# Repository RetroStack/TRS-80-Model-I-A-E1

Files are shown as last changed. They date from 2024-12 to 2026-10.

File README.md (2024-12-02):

# TRS-80 Model 1 (Rev A) Replica - E1

This project is a reverse-engineered PCB created to document the mainboard of the iconic TRS-80 Model 1 (Revision A) computer. Released in 1977, Revision A was the first implementation and features some differences compared to later revisions, including a different Z3 selector, a slightly modified video sync circuit, and a lack of support for 8k dynamic RAM.

The entire project is available under the MIT license.

**NOTE:** The PCB has not yet been validated. Once I am able to fully validate the PCB by producing a board and thoroughly testing it, I will make the Gerber files available. Additionally, I will have some PCBs available in my [store](https://shop.retrostack.org).

## Project Details

### Latest Files

In the "Latest" folder, you'll find the most up-to-date design files, including:

- The [full schematics](/Latest/TRS80_Model_I_A_E1_Schematics.pdf) of the E1 replica which is 1:1 to the original G board.

### Implementation

E1 has been implemented using KiCAD 8. The KiCAD project files are included in this repository.

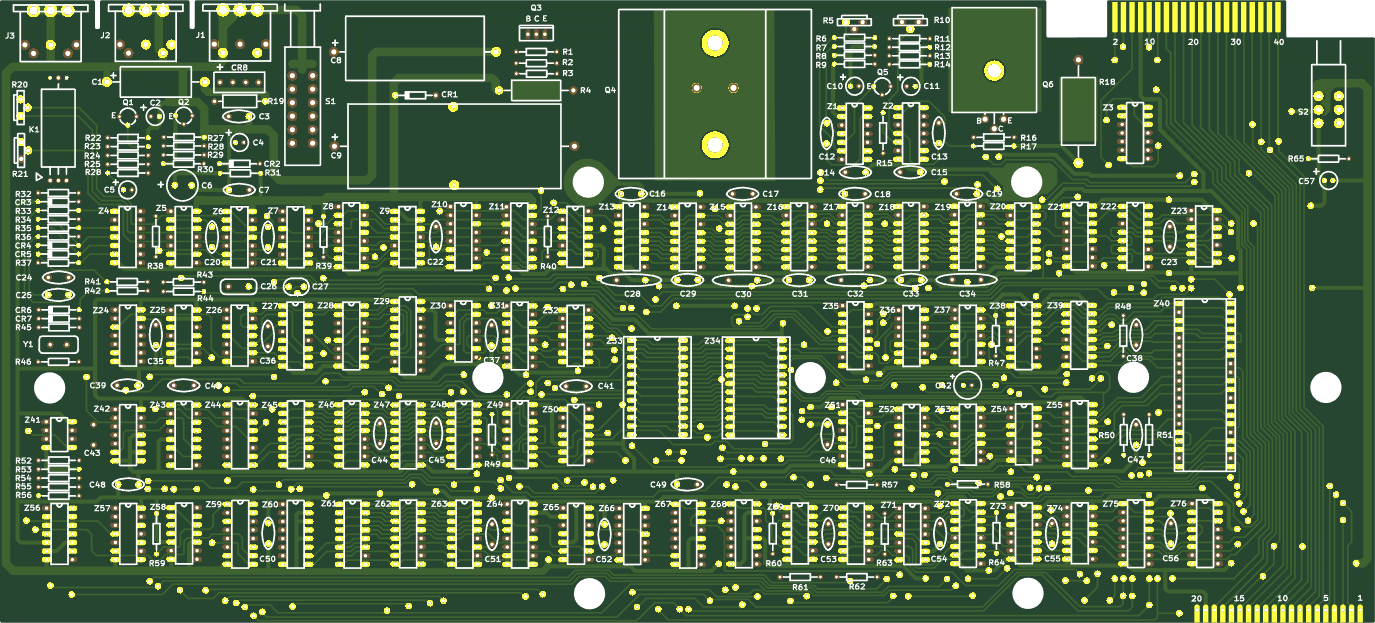
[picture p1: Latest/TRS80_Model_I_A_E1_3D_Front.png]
E1 Replica Front

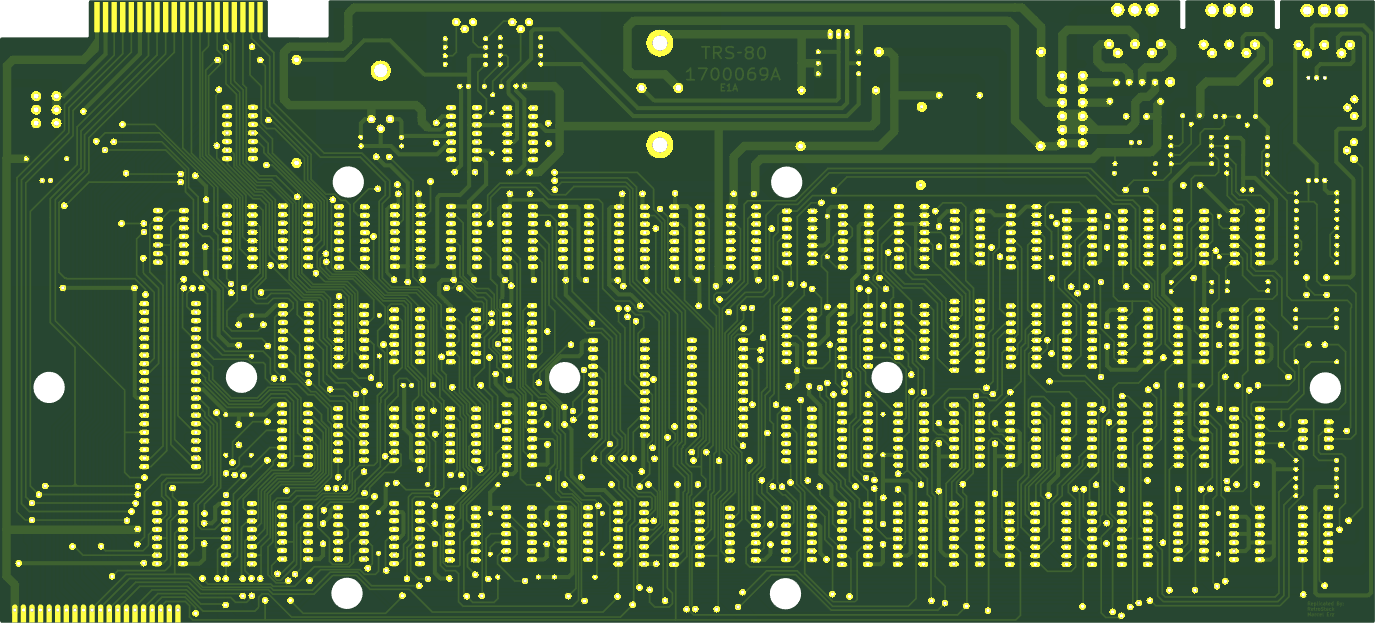
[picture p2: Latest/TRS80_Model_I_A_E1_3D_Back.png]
E1 Replica Back


### RetroStack Libraries

To work with this KiCAD project, you'll need the RetroStack libraries for KiCAD. Please [follow this link](https://www.github.com/RetroStack/KiCAD-Libraries) to access and install these libraries.

## Main TRS-80 Model 1 Repository

For additional resources related to the TRS-80 Model 1, be sure to check out the [central page for the TRS-80 Model 1](https://www.github.com/RetroStack/TRS-80-Model-I) on [RetroStack](https://www.github.com/RetroStack).

## Support this Project

RetroStack is passionate about exploring and preserving the legacy of older computer systems. My work involves creating detailed documentation and videos to share the knowledge. I am also dedicated to reviving these classic systems by reimplementing them and offering replacement parts at no cost. If you're keen on supporting this unique project, I invite you to visit my [Patreon page](https://www.patreon.com/RetroStack). Your support would be immensely valuable and greatly appreciated!

## License

This project is licensed under the MIT License - see the [LICENSE](LICENSE) file for details.

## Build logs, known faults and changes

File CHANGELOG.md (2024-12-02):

# TRS-80 Model 1 (Rev A) Replica - E1 - Changelog

## 30th Nov 2024 - E1A

Completed. Untested.

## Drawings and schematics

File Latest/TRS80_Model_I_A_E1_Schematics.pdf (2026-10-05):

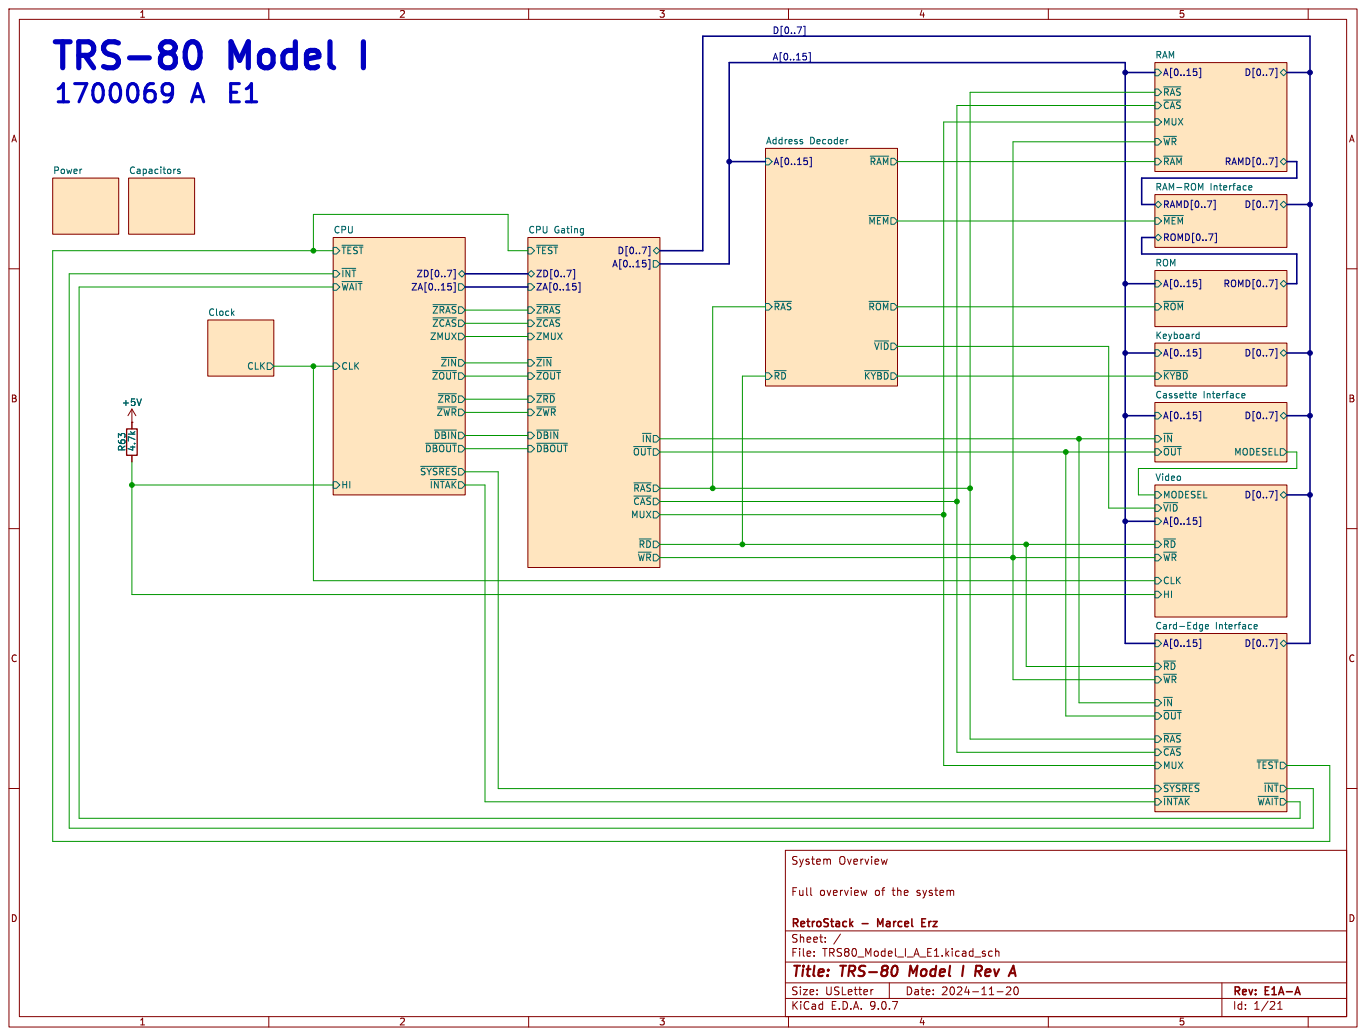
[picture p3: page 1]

RAMD[0..7] RAM-ROM Interface ~{WR}
~{RAM}
D[0..7] MODESEL Cassette Interface ~{RAS}

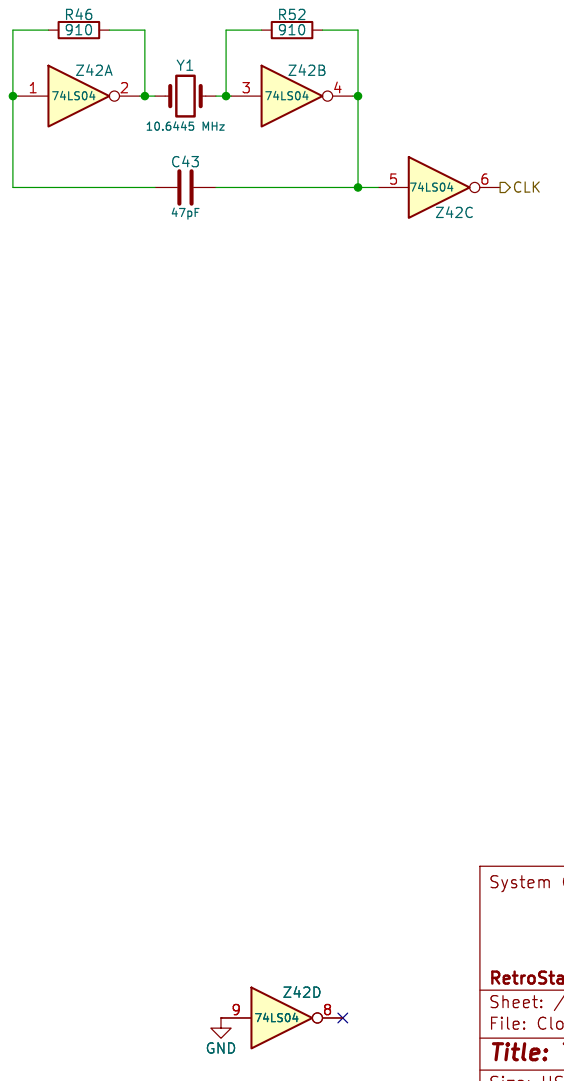
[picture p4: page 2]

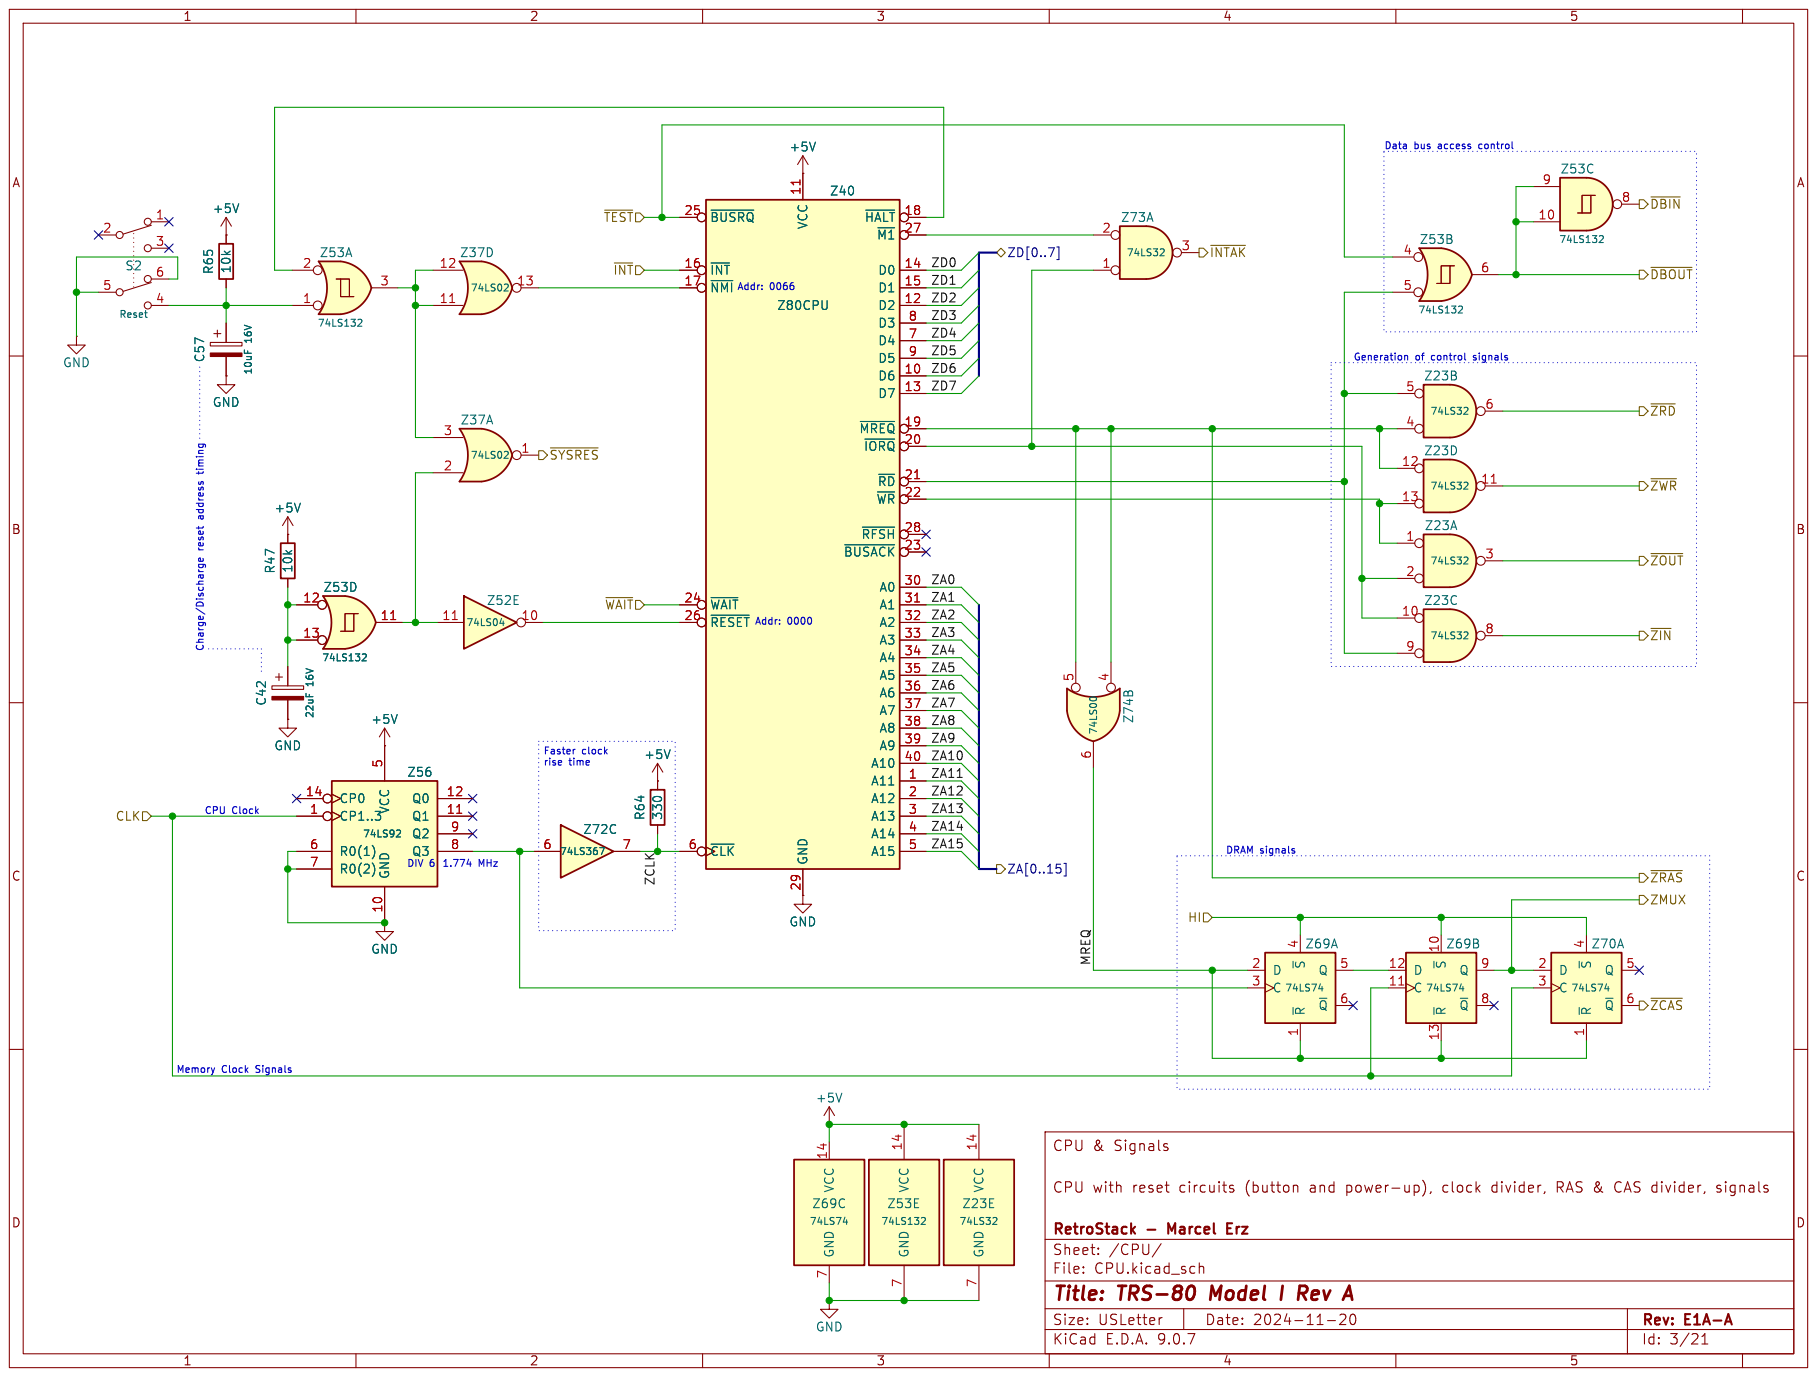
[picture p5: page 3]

rise time CPU Clock

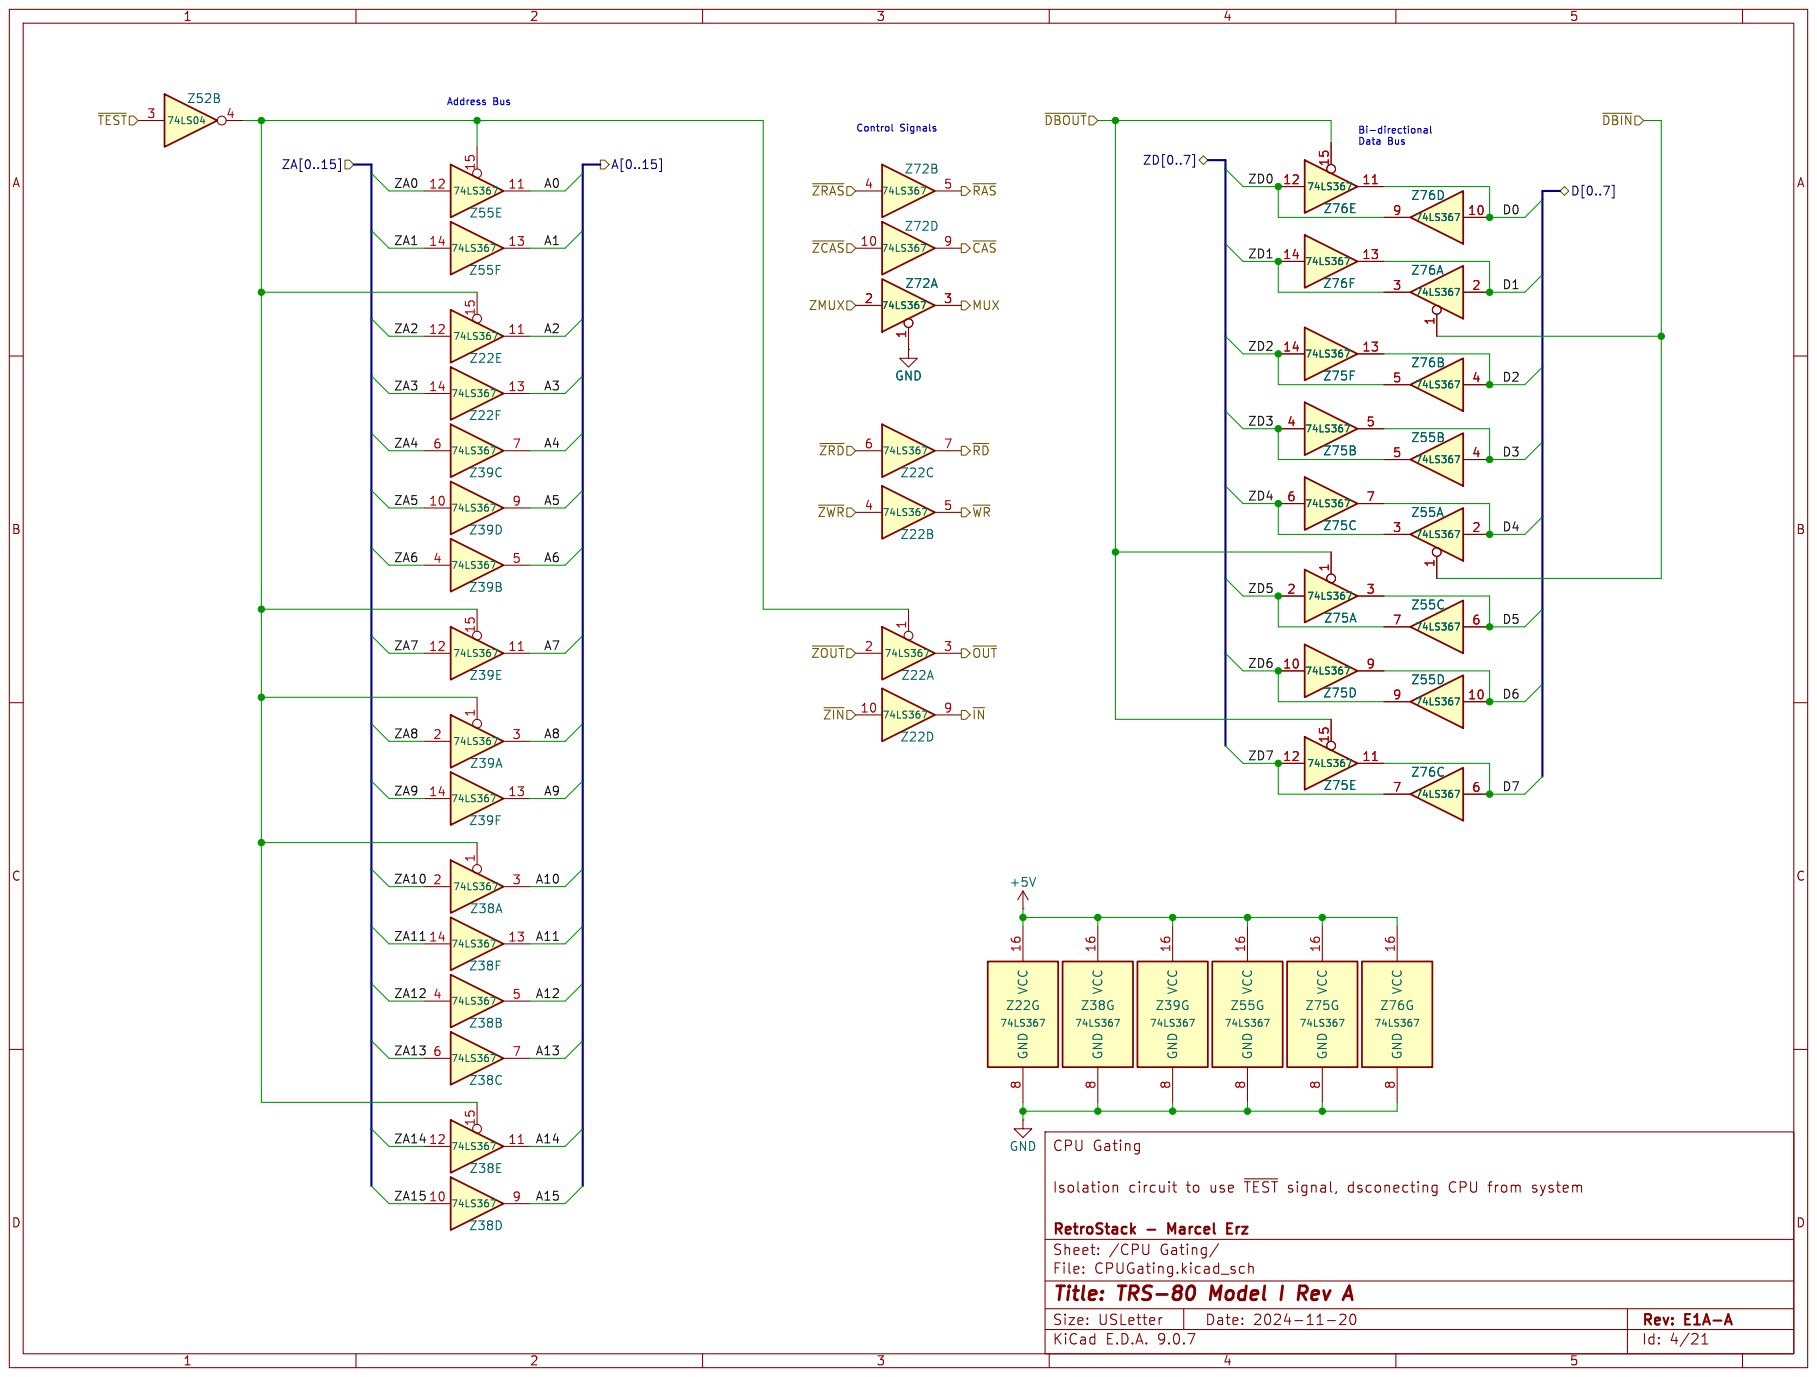
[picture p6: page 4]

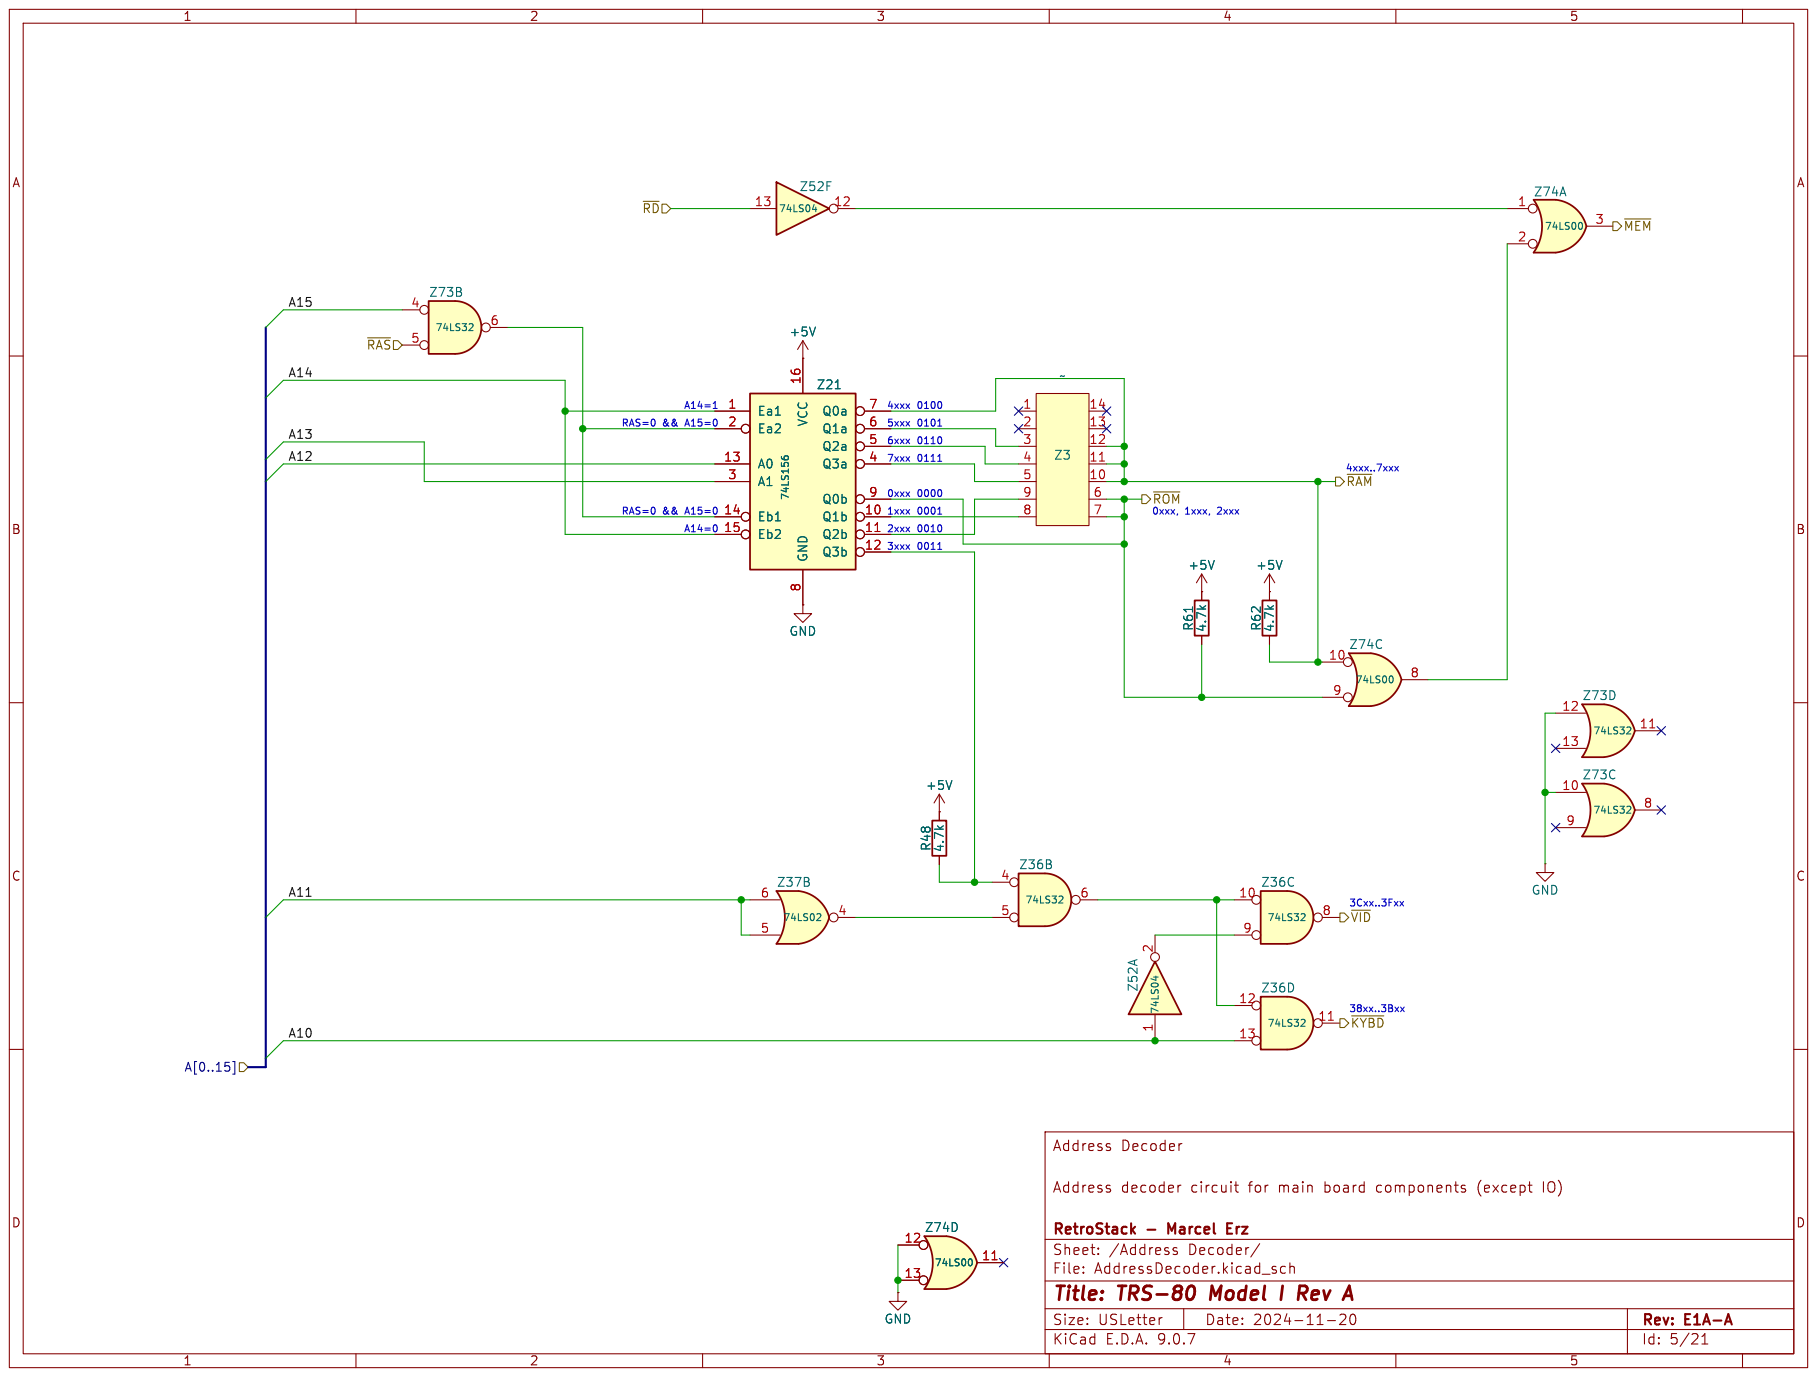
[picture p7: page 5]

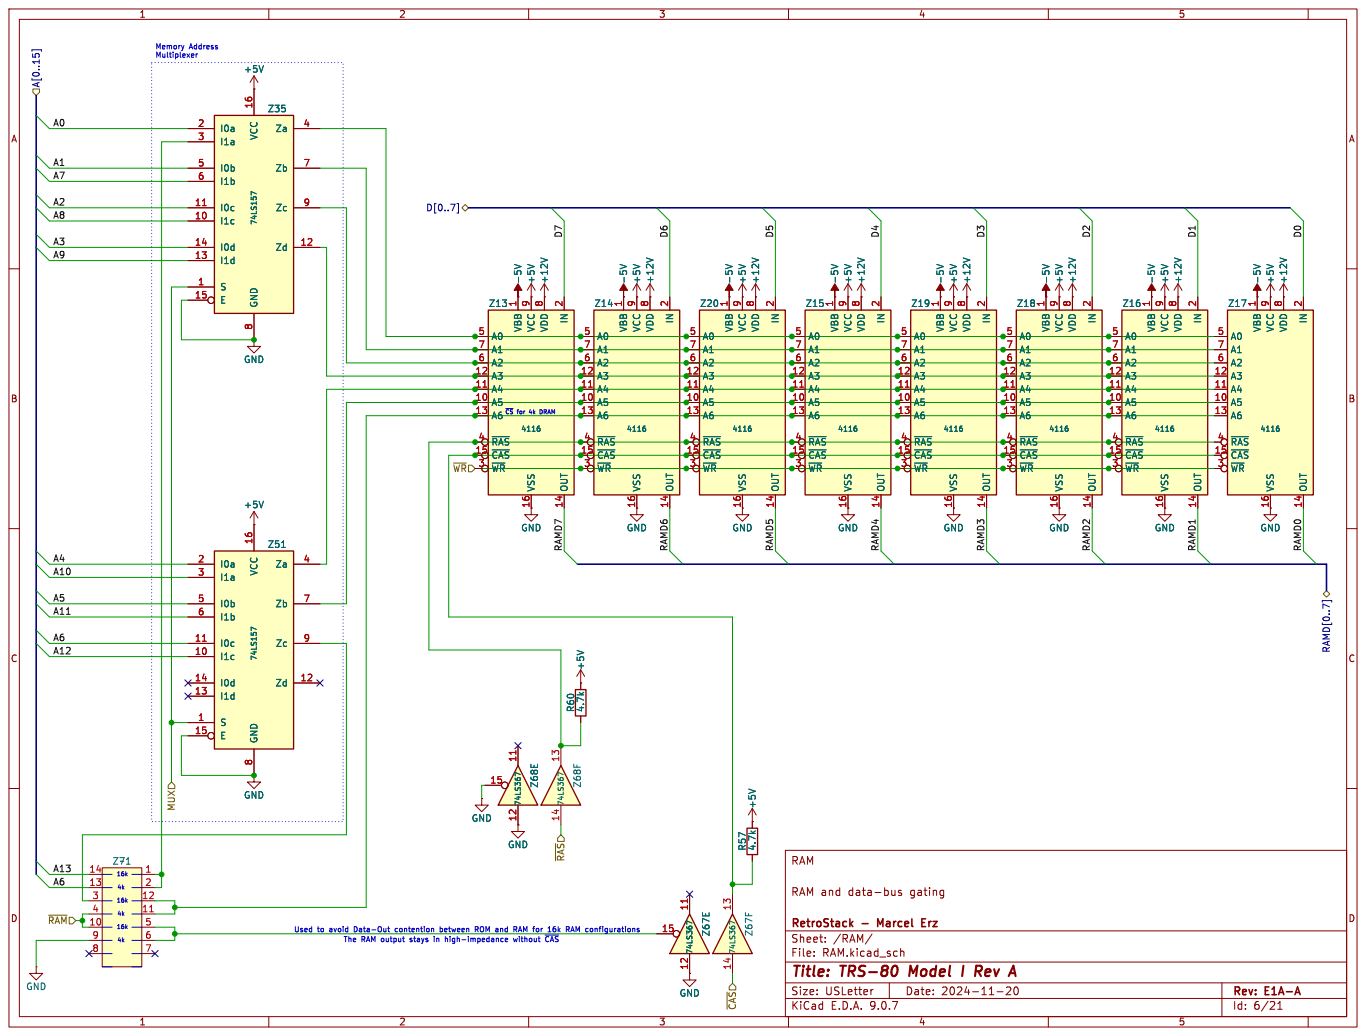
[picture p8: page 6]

8 Za 4 Zb 7 Zc 9 Zd 12 Z35 74LS157 +5V GND

8 Za 4 Zb 7 Zc 9 Zd 12 +5V GND

8 Za 4 Zb 7 Zc 9 Zd 12 GND -5V +5V

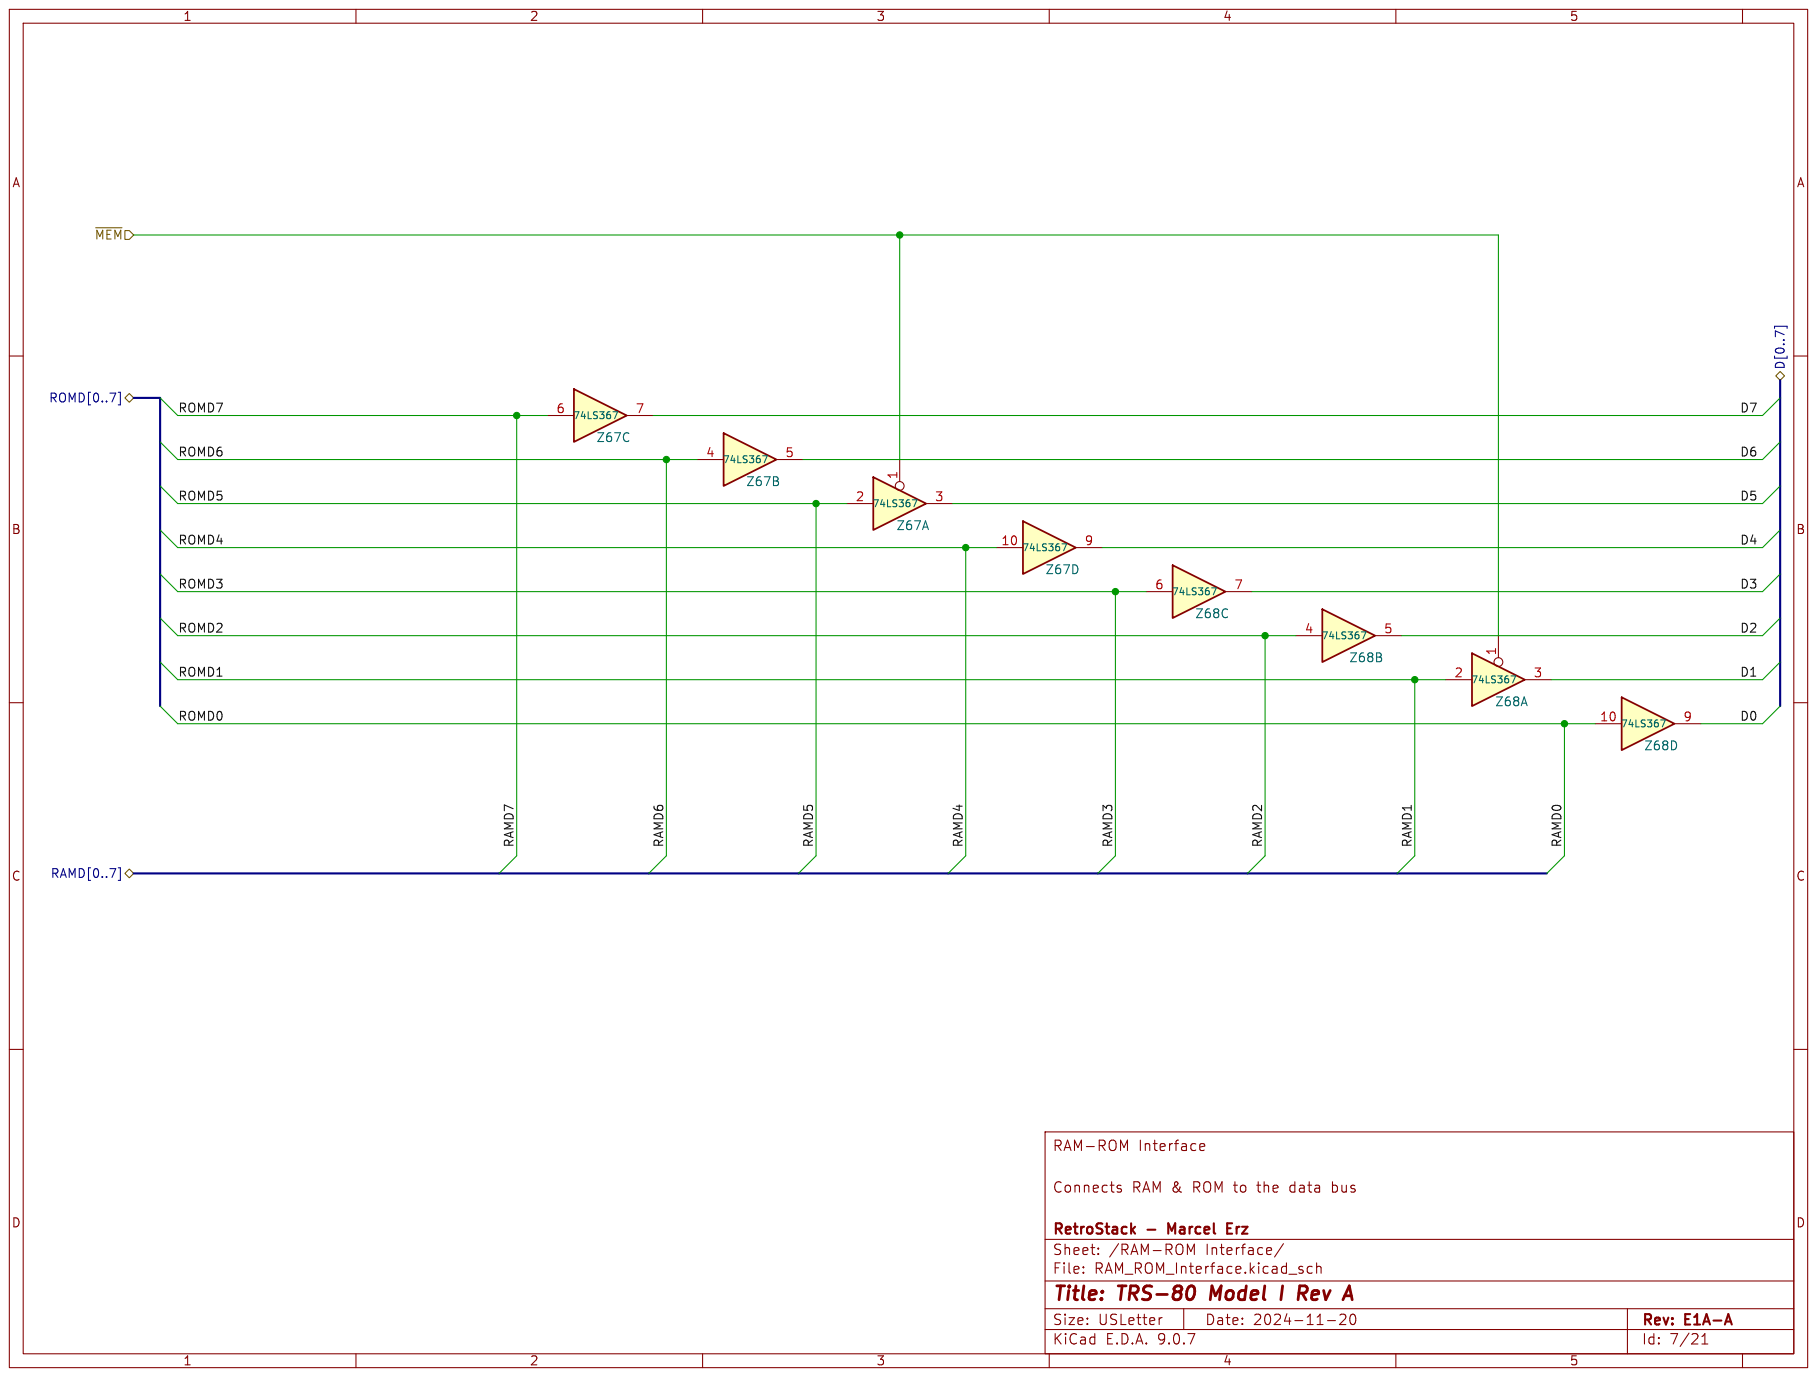
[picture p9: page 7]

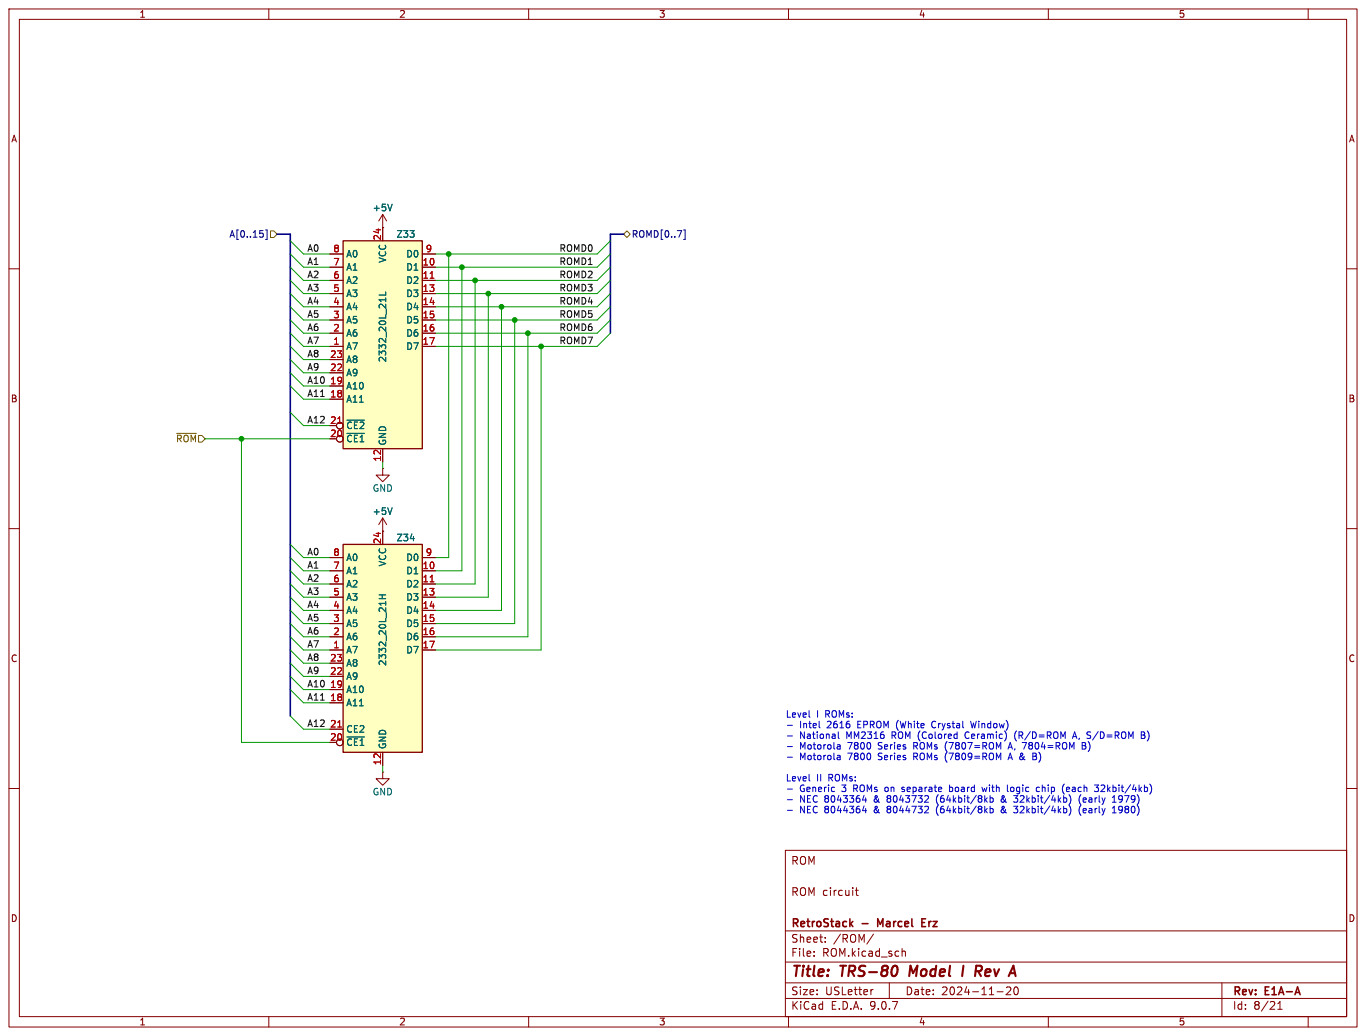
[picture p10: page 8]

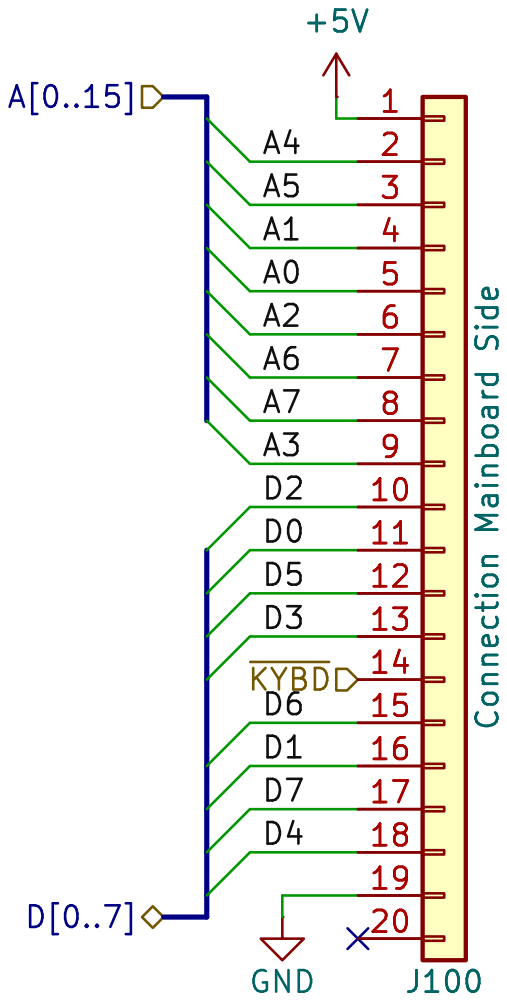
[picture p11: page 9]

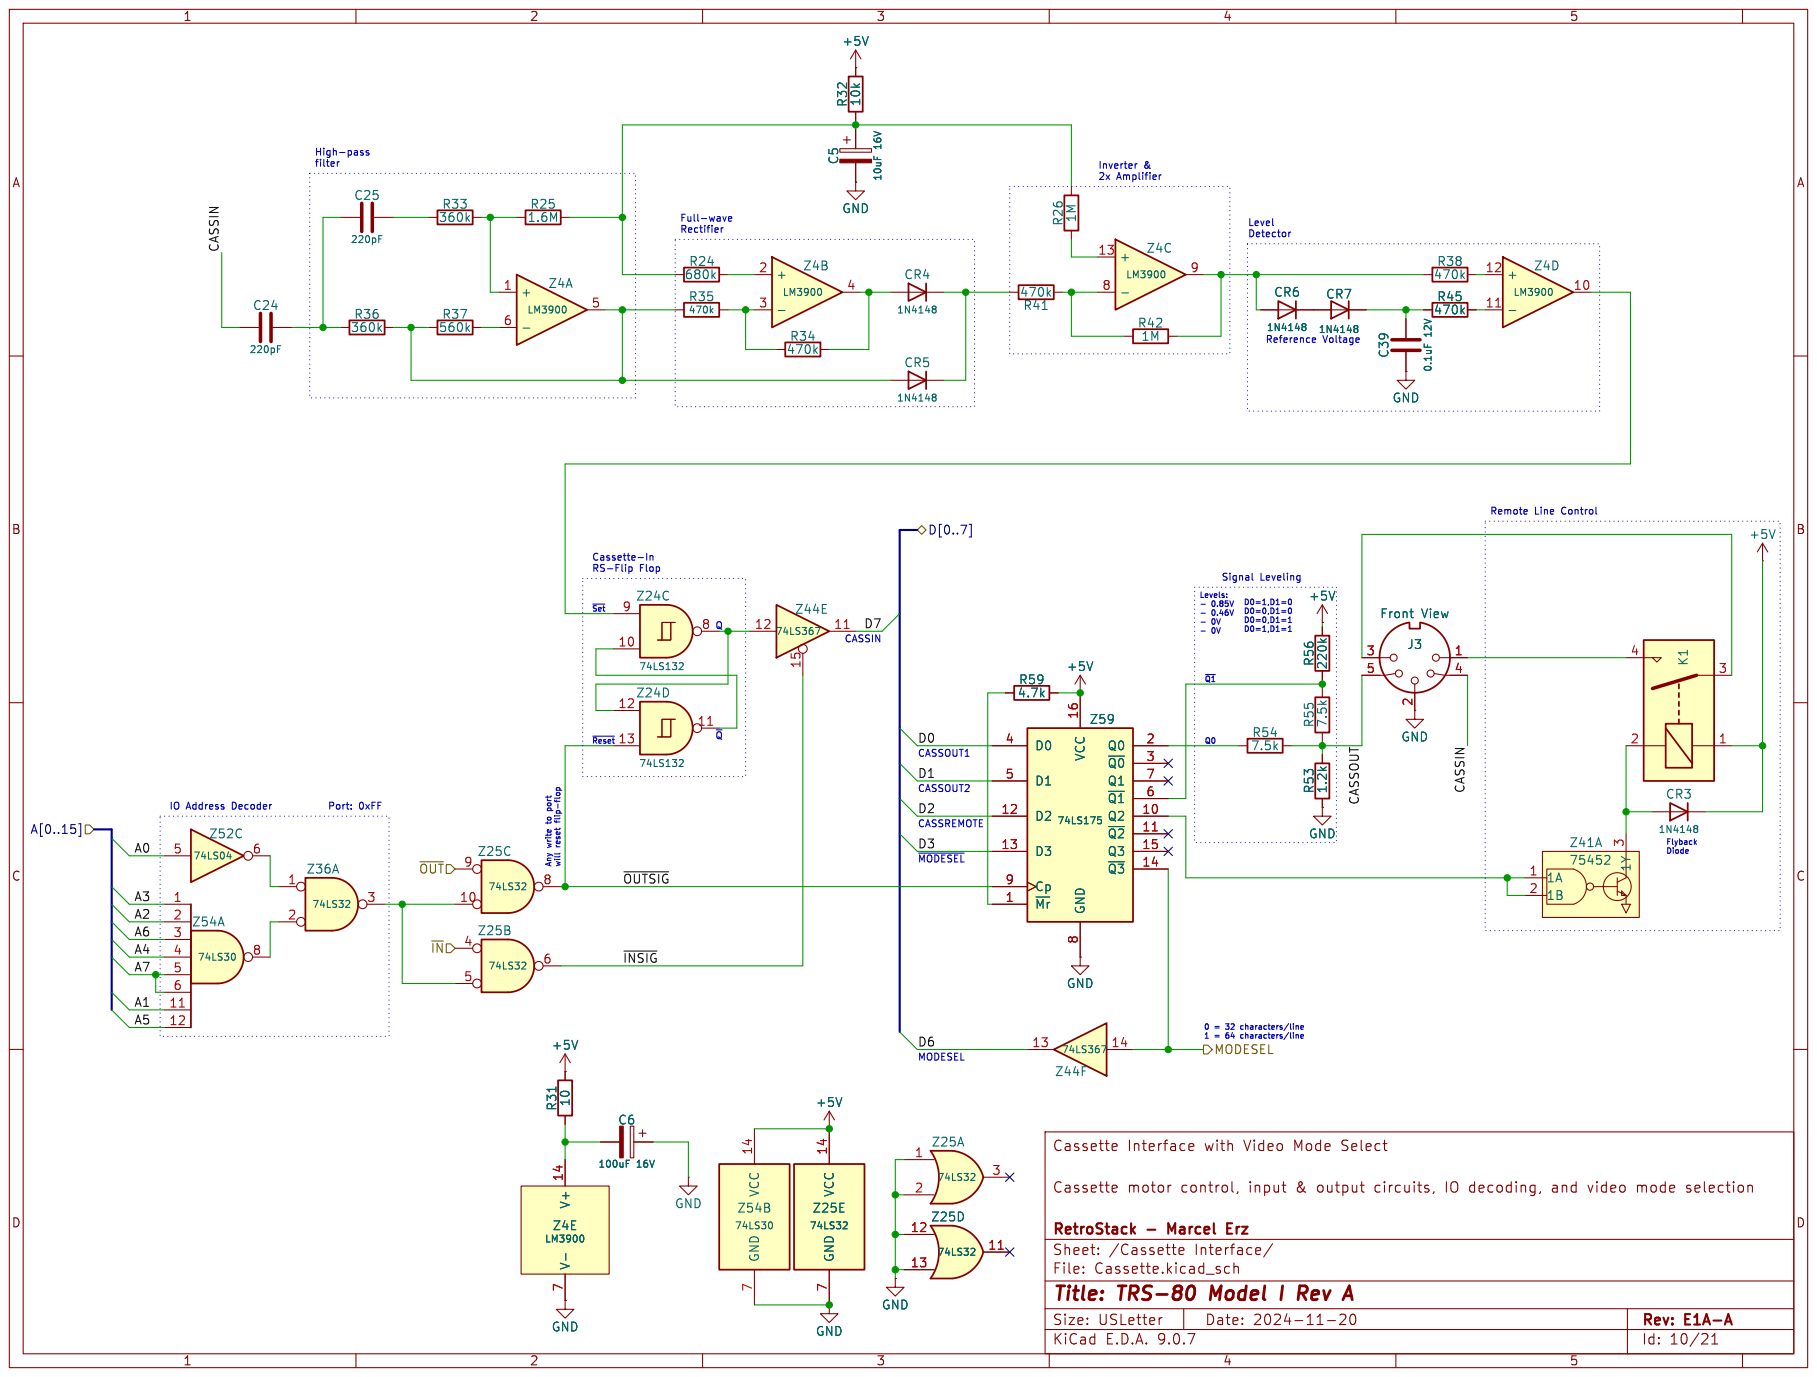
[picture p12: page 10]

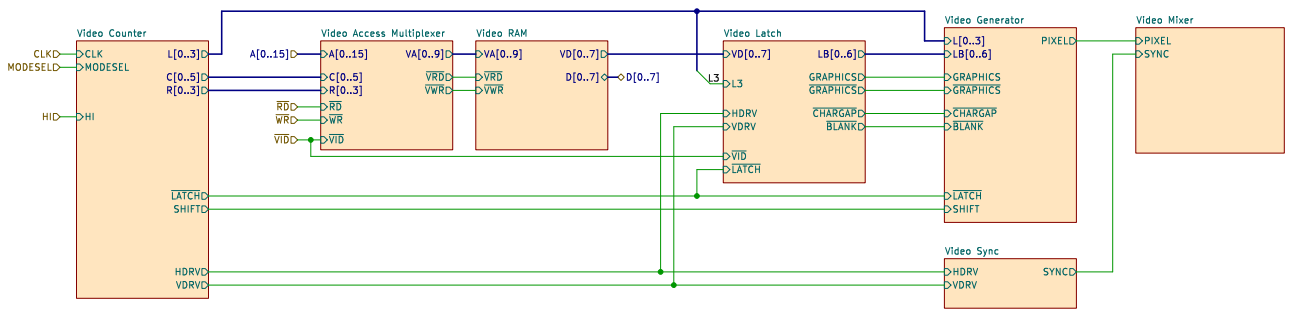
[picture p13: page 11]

LB[0..6] Video Generator D[0..7] MODESELHI CLK

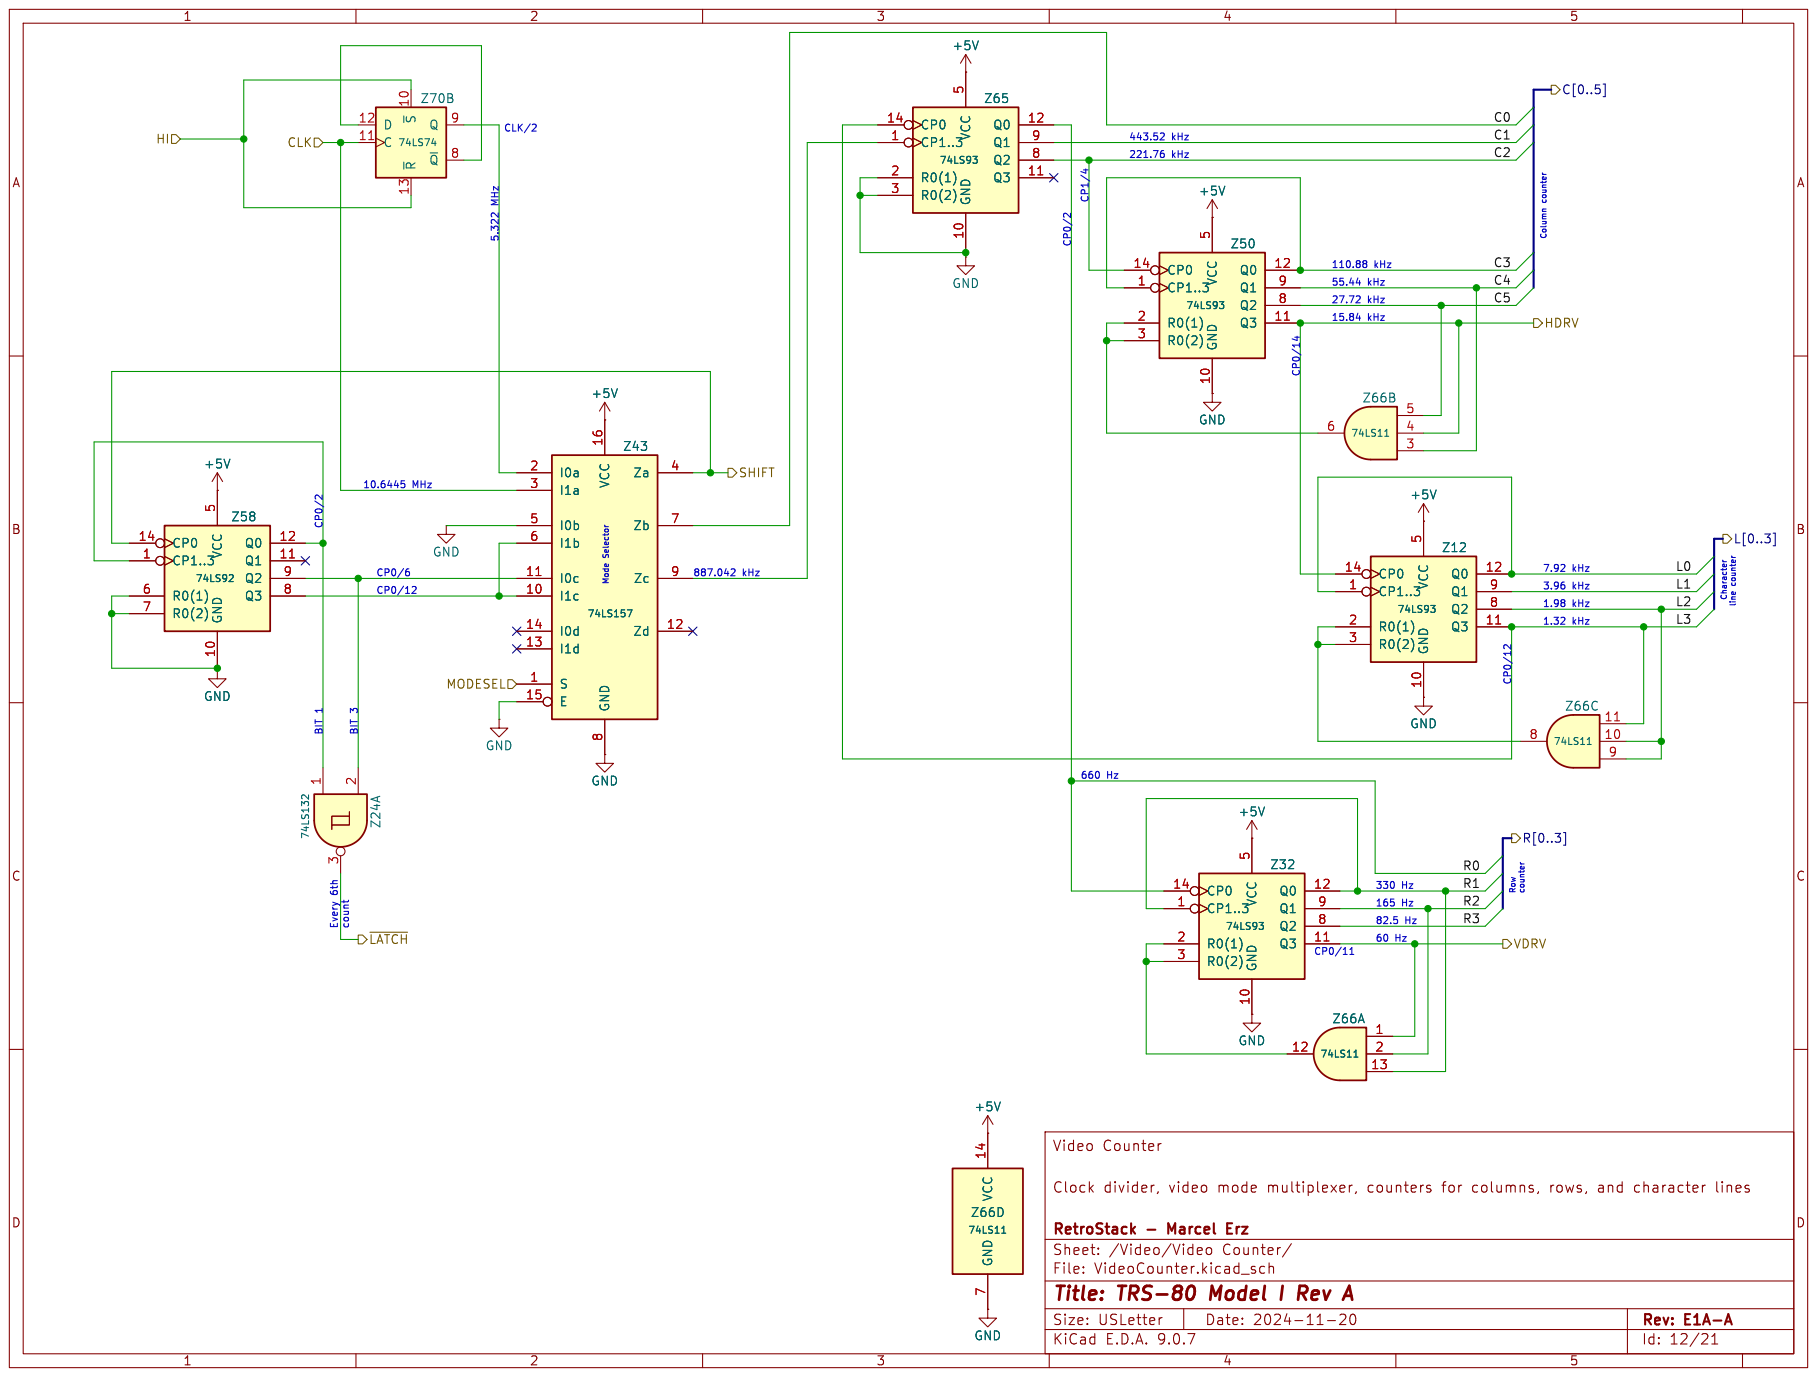
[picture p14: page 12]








12 ~{OUT} 14 ~{INTAK} 16 18 20 22 24 26 28 30 32 34



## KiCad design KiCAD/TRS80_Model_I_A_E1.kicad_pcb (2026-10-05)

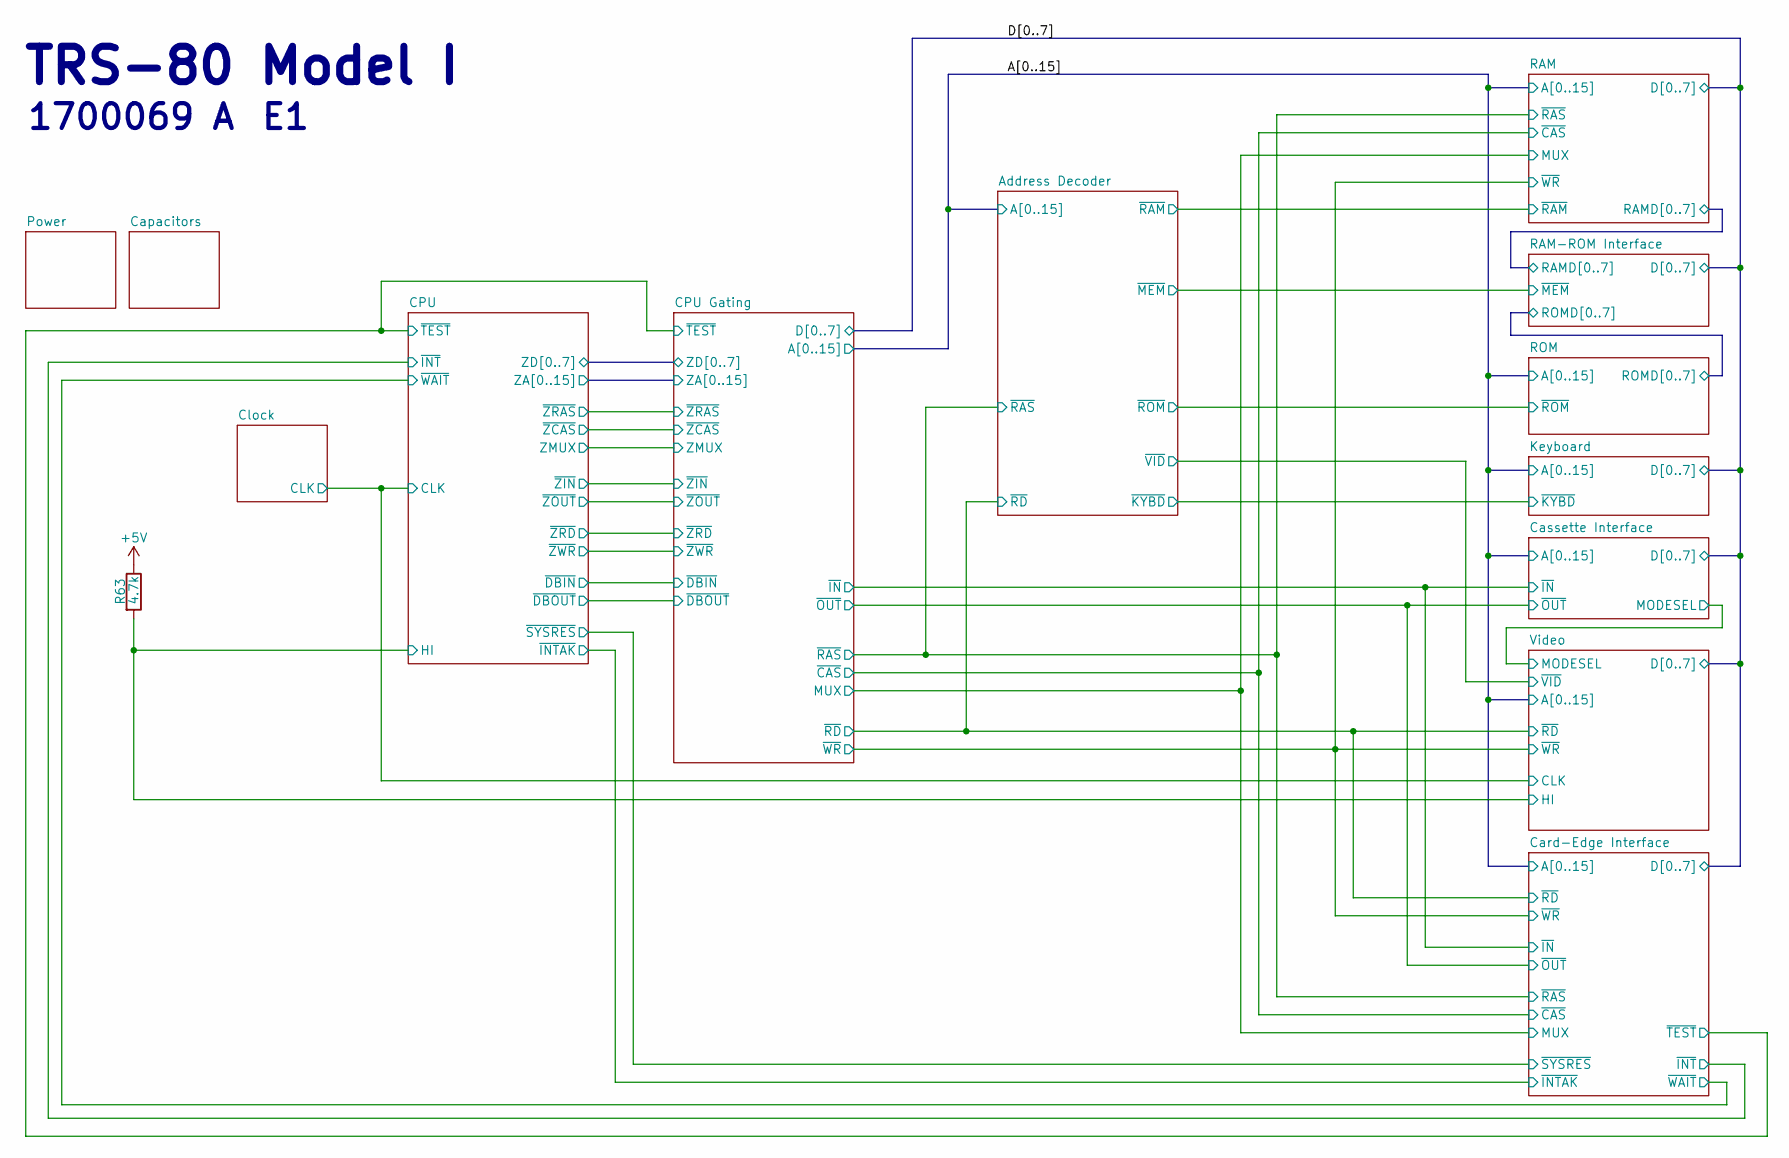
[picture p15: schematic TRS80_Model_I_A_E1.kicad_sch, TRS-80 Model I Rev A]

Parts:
R63: 4.7k; TRS80_Model_I_R_0.25W

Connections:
+5V: R63.1; also elsewhere on the board
/CPU/HI: R63.2; also elsewhere on the board

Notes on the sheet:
TRS-80 Model I
1700069 A

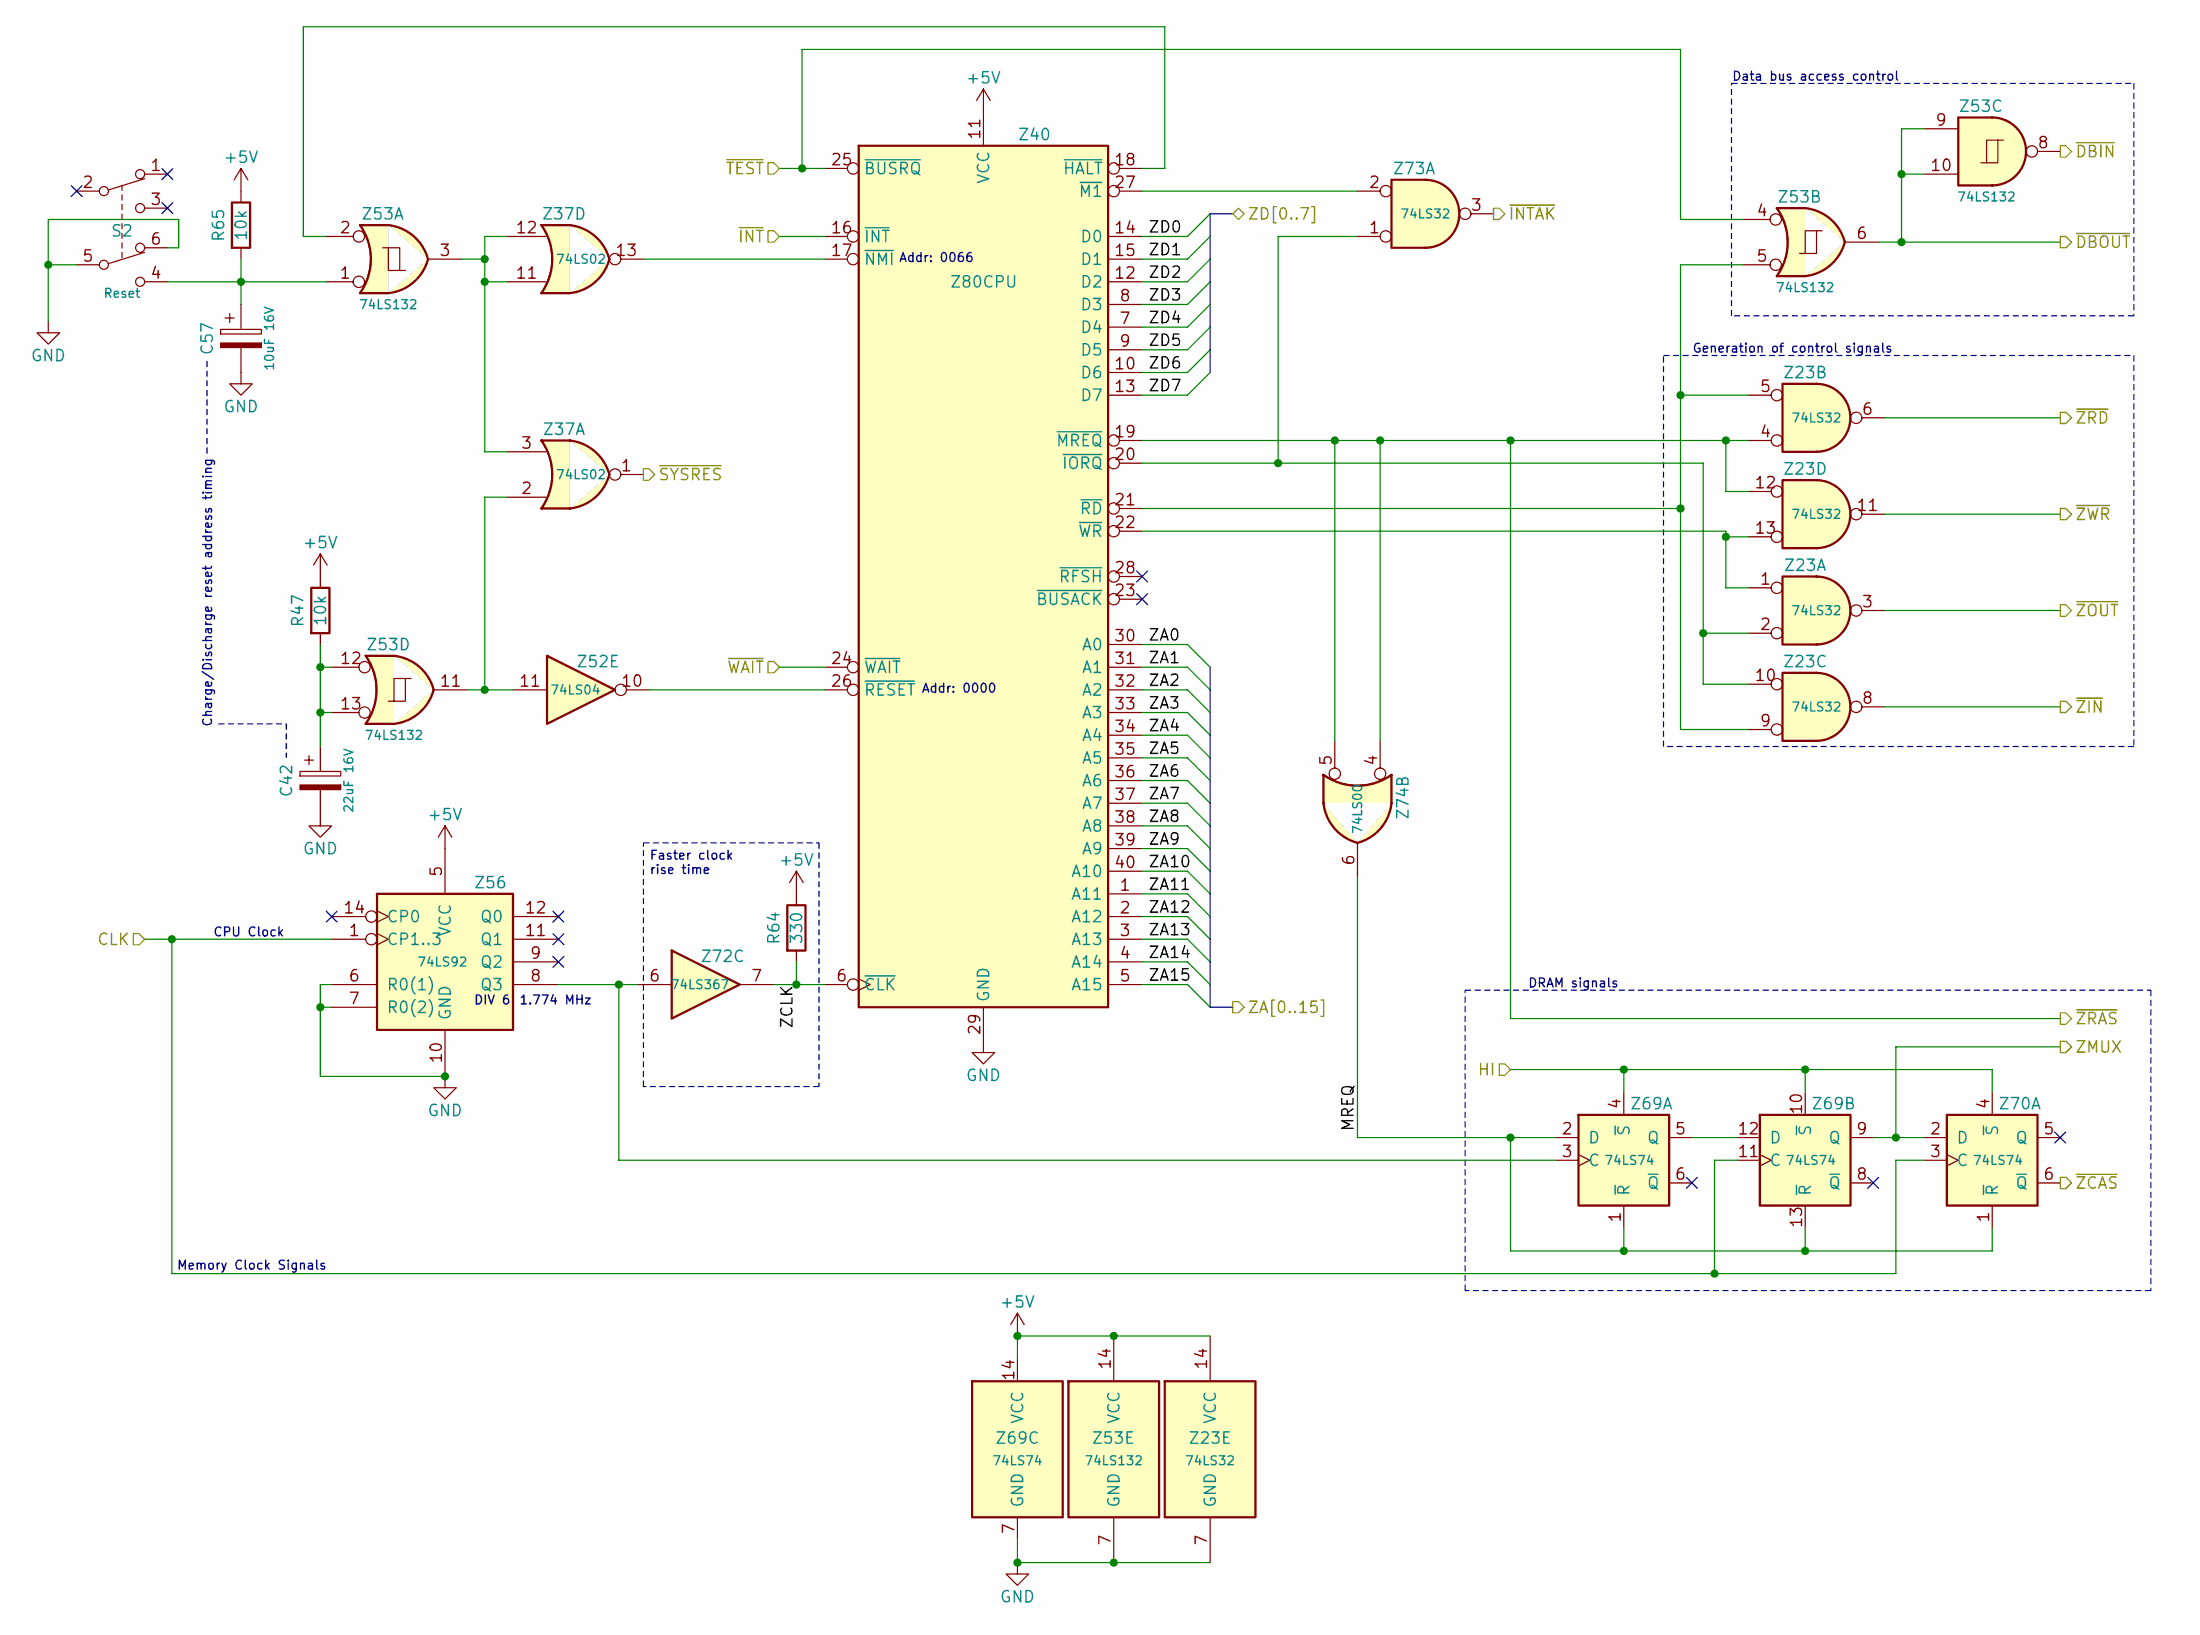
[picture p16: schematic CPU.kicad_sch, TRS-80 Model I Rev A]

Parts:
C42: 22uF 16V; TRS80_Model_I_C_Pol_Radial_6.3D_2.5P
C57: 10uF 16V; TRS80_Model_I_C_Pol_Radial_5D_2.5P
R47, R65: 10k; TRS80_Model_I_R_0.25W
R64: 330; TRS80_Model_I_R_0.25W
S2: Reset; TRS80_Model_I_Sw_Small
Z23, Z73: 74LS32; TRS80_Model_I_DIP14
Z37: 74LS02; TRS80_Model_I_DIP14
Z40: Z80CPU; TRS80_Model_I_DIP40
Z52: 74LS04; TRS80_Model_I_DIP14
Z53: 74LS132; TRS80_Model_I_DIP14
Z56: 74LS92; TRS80_Model_I_DIP14
Z69, Z70: 74LS74; TRS80_Model_I_DIP14
Z72: 74LS367; TRS80_Model_I_DIP16
Z74: 74LS00; TRS80_Model_I_DIP14

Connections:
+5V: R47.1, R64.1, R65.1, Z23.14 (VCC), Z40.11 (VCC), Z53.14 (VCC), Z56.5 (VCC), Z69.14 (VCC); also elsewhere on the board
/CPU Gating/ZA0: Z40.30 (A0); also elsewhere on the board
/CPU Gating/ZA1: Z40.31 (A1); also elsewhere on the board
/CPU Gating/ZA2: Z40.32 (A2); also elsewhere on the board
/CPU Gating/ZA3: Z40.33 (A3); also elsewhere on the board
/CPU Gating/ZA4: Z40.34 (A4); also elsewhere on the board
/CPU Gating/ZA5: Z40.35 (A5); also elsewhere on the board
/CPU Gating/ZA6: Z40.36 (A6); also elsewhere on the board
/CPU Gating/ZA7: Z40.37 (A7); also elsewhere on the board
/CPU Gating/ZA8: Z40.38 (A8); also elsewhere on the board
/CPU Gating/ZA9: Z40.39 (A9); also elsewhere on the board
/CPU Gating/ZA10: Z40.40 (A10); also elsewhere on the board
/CPU Gating/ZA11: Z40.1 (A11); also elsewhere on the board
/CPU Gating/ZA12: Z40.2 (A12); also elsewhere on the board
/CPU Gating/ZA13: Z40.3 (A13); also elsewhere on the board
/CPU Gating/ZA14: Z40.4 (A14); also elsewhere on the board
/CPU Gating/ZA15: Z40.5 (A15); also elsewhere on the board
/CPU Gating/ZD0: Z40.14 (D0); also elsewhere on the board
/CPU Gating/ZD1: Z40.15 (D1); also elsewhere on the board
/CPU Gating/ZD2: Z40.12 (D2); also elsewhere on the board
/CPU Gating/ZD3: Z40.8 (D3); also elsewhere on the board
/CPU Gating/ZD4: Z40.7 (D4); also elsewhere on the board
/CPU Gating/ZD5: Z40.9 (D5); also elsewhere on the board
/CPU Gating/ZD6: Z40.10 (D6); also elsewhere on the board
/CPU Gating/ZD7: Z40.13 (D7); also elsewhere on the board
/CPU Gating/ZMUX: Z69.9 (Q), Z70.2 (D); also elsewhere on the board
/CPU Gating/~DBIN: Z53.8; also elsewhere on the board
/CPU Gating/~DBOUT: Z53.6, Z53.9, Z53.10; also elsewhere on the board
/CPU Gating/~TEST: Z40.25 (~BUSRQ), Z53.4; also elsewhere on the board
/CPU Gating/~ZCAS: Z70.6 (~Q); also elsewhere on the board
/CPU Gating/~ZIN: Z23.8; also elsewhere on the board
/CPU Gating/~ZOUT: Z23.3; also elsewhere on the board
/CPU Gating/~ZRAS: Z23.4, Z23.12, Z40.19 (~MREQ), Z74.4, Z74.5; also elsewhere on the board
/CPU Gating/~ZRD: Z23.6; also elsewhere on the board
/CPU Gating/~ZWR: Z23.11; also elsewhere on the board
/CPU/CLK: Z56.1 (CP1..3), Z69.11 (C), Z70.3 (C); also elsewhere on the board
/CPU/HI: Z69.4 (~S), Z69.10 (~S), Z70.4 (~S); also elsewhere on the board
/CPU/MREQ: Z69.1 (~R), Z69.2 (D), Z69.13 (~R), Z70.1 (~R), Z74.6
/CPU/ZCLK: R64.2, Z40.6 (~CLK), Z72.7
/CPU/~INTAK: Z73.3; also elsewhere on the board
/CPU/~INT: Z40.16 (~INT); also elsewhere on the board
/CPU/~SYSRES: Z37.1; also elsewhere on the board
/CPU/~WAIT: Z40.24 (~WAIT); also elsewhere on the board
GND: C42.2, C57.2, S2.5, S2.6, Z23.7 (GND), Z40.29 (GND), Z53.7 (GND), Z56.6 (R0(1)), Z56.7 (R0(2)), Z56.10 (GND), Z69.7 (GND); also elsewhere on the board
unnamed: C42.1, R47.2, Z53.12, Z53.13
unnamed: C57.1, R65.2, S2.4, Z53.1
unnamed: Z37.2, Z52.11, Z53.11
unnamed: Z37.3, Z37.11, Z37.12, Z53.3
unnamed: Z40.18 (~HALT), Z53.2
unnamed: Z23.2, Z23.10, Z40.20 (~IORQ), Z73.1
unnamed: Z40.27 (~M1), Z73.2
unnamed: Z37.13, Z40.17 (~NMI)
unnamed: Z23.5, Z23.9, Z40.21 (~RD), Z53.5
unnamed: Z40.26 (~RESET), Z52.10
unnamed: Z23.1, Z23.13, Z40.22 (~WR)
unnamed: Z56.8 (Q3), Z69.3 (C), Z72.6
unnamed: Z69.5 (Q), Z69.12 (D)

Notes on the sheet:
Data bus access control
DIV 6
Generation of control signals
DRAM signals
1.774 MHz
Faster clock rise time
Memory Clock Signals
CPU Clock
Addr: 0000
Charge/Discharge reset address timing
Addr: 0066

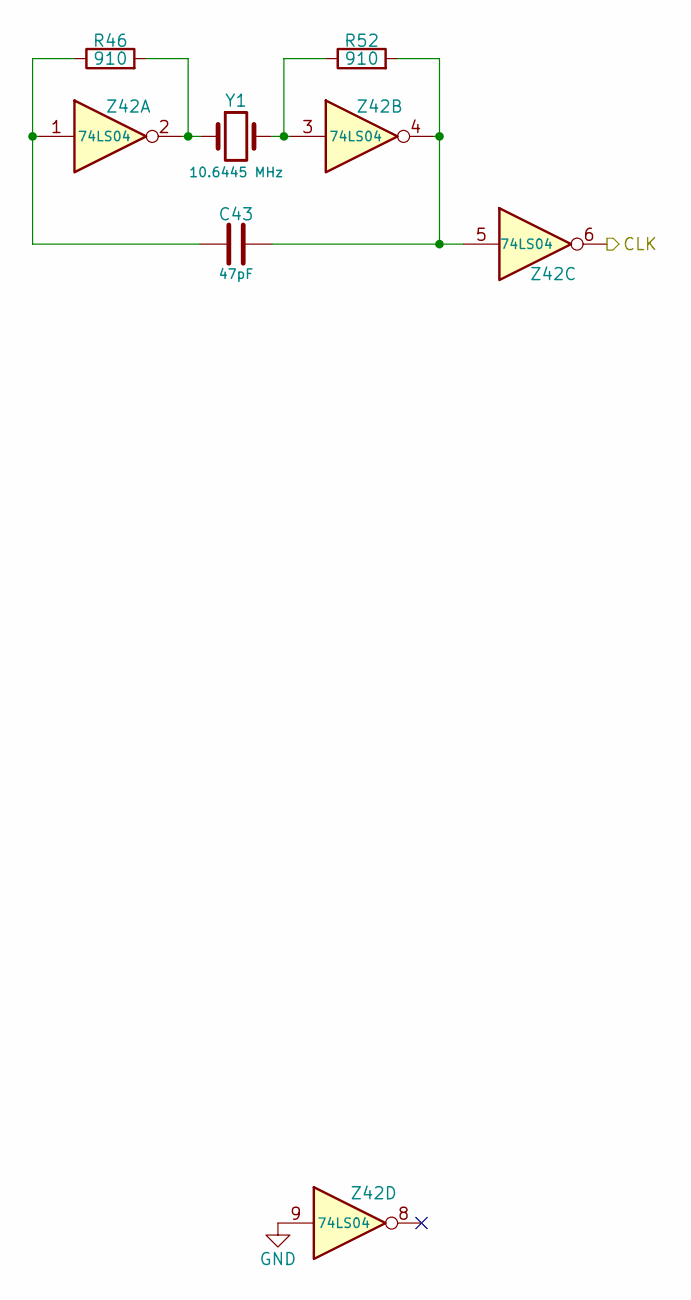
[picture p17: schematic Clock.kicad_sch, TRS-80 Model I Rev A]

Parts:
C43: 47pF; TRS80_Model_I_C_Disc_9.5L_4W_6P_Small
R46, R52: 910; TRS80_Model_I_R_0.25W
Y1: 10.6445 MHz; TRS80_Model_I_Crystal
Z42: 74LS04; TRS80_Model_I_DIP14

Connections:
/CPU/CLK: Z42.6; also elsewhere on the board
GND: Z42.9; also elsewhere on the board
unnamed: C43.1, R46.1, Z42.1
unnamed: C43.2, R52.2, Z42.4, Z42.5
unnamed: R46.2, Y1.1, Z42.2
unnamed: R52.1, Y1.2, Z42.3

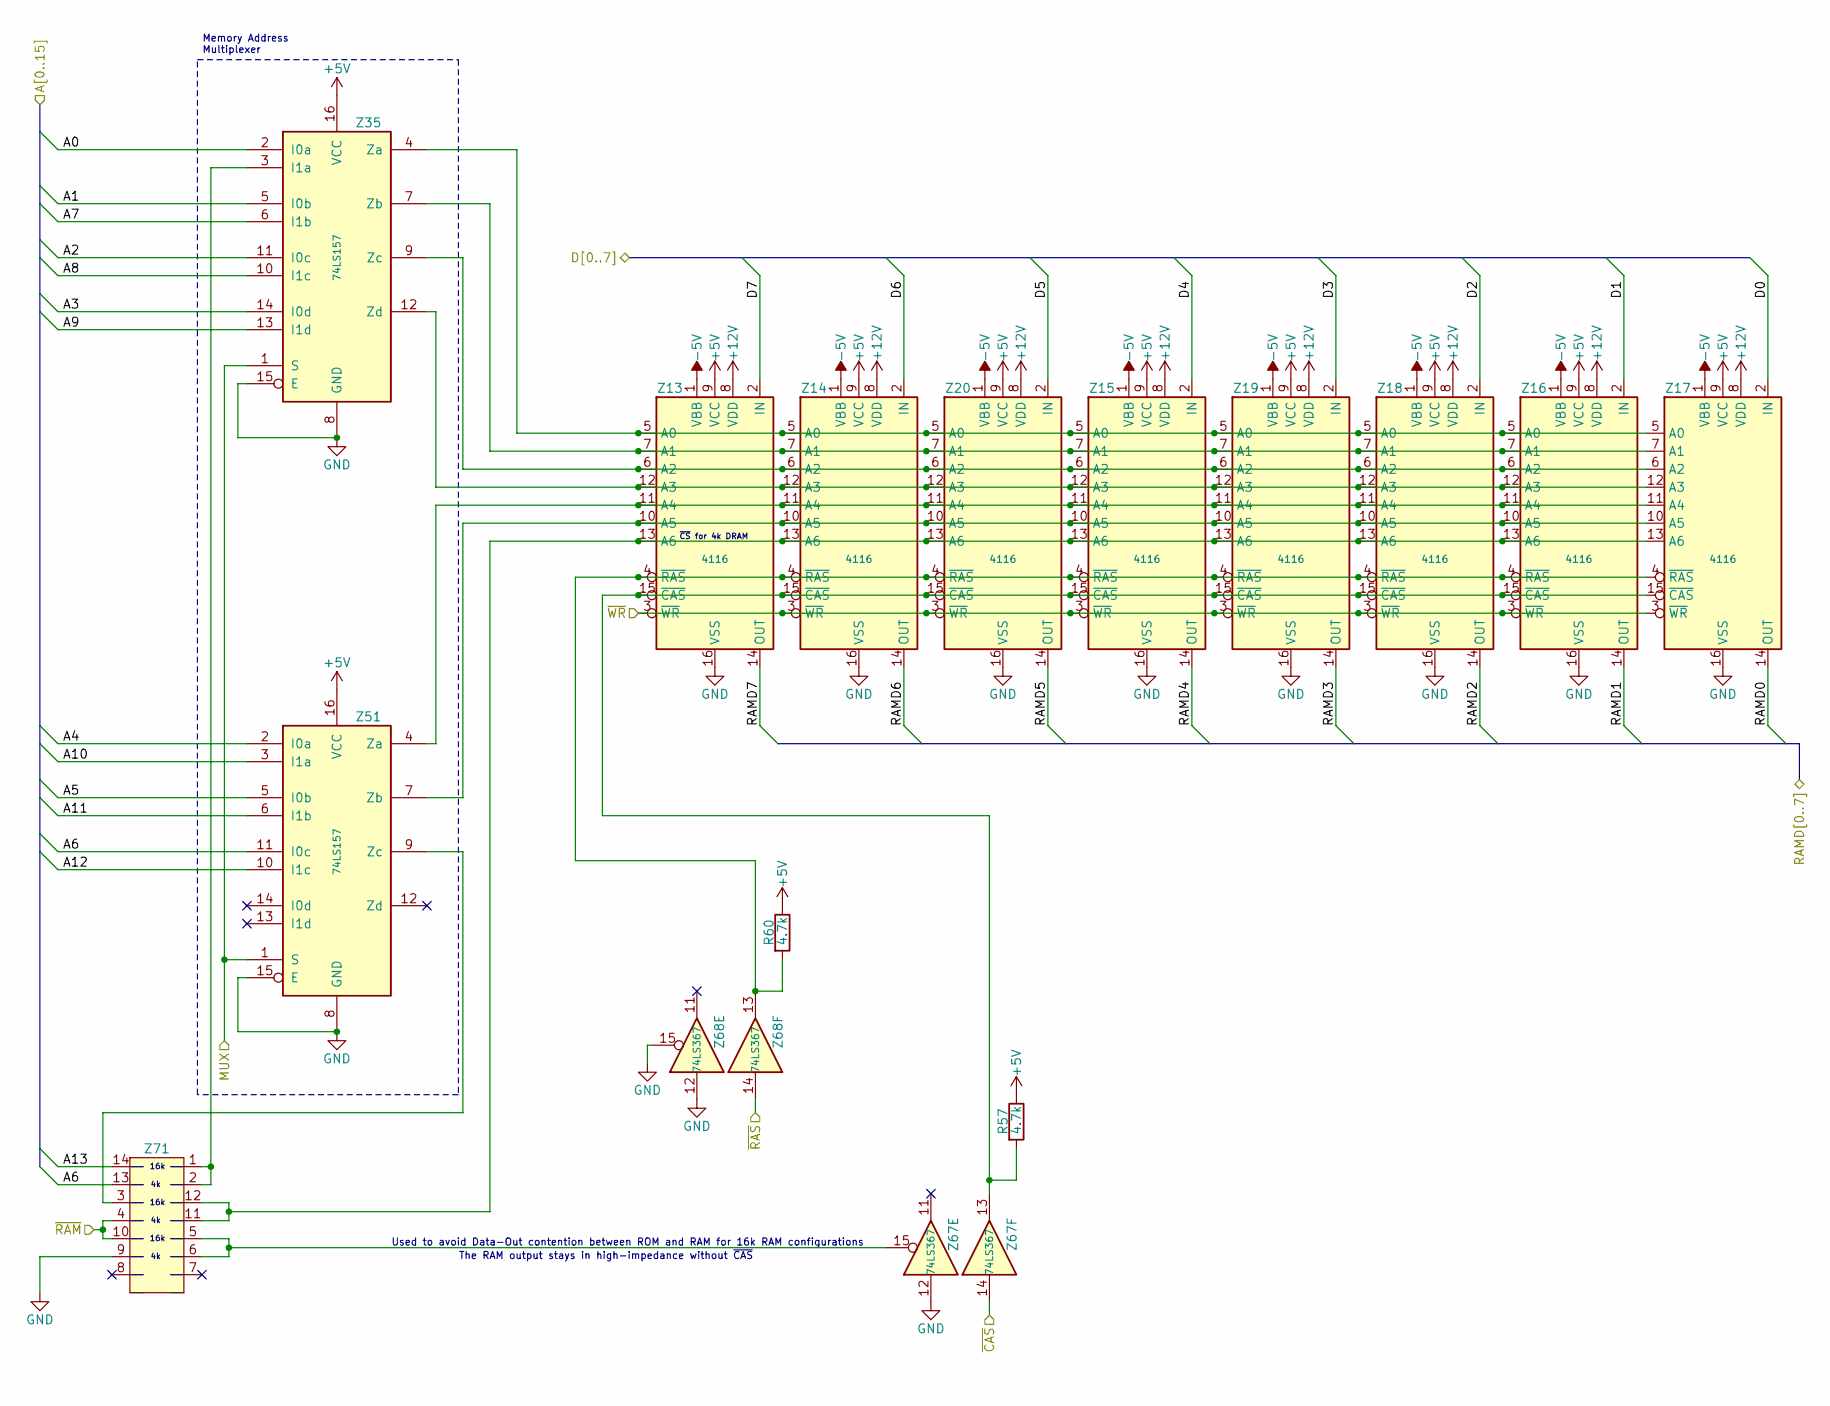
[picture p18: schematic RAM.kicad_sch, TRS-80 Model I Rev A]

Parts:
R57, R60: 4.7k; TRS80_Model_I_R_0.25W
Z13, Z14, Z15, Z16, Z17, Z18, Z19, Z20: 4116; TRS80_Model_I_DIP16
Z35, Z51: 74LS157; TRS80_Model_I_DIP16
Z67, Z68: 74LS367; TRS80_Model_I_DIP16
Z71: TRS80_Model_I_DIP14

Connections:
+5V: R57.1, R60.1, Z13.9 (VCC), Z14.9 (VCC), Z15.9 (VCC), Z16.9 (VCC), Z17.9 (VCC), Z18.9 (VCC), Z19.9 (VCC), Z20.9 (VCC), Z35.16 (VCC), Z51.16 (VCC); also elsewhere on the board
+12V: Z13.8 (VDD), Z14.8 (VDD), Z15.8 (VDD), Z16.8 (VDD), Z17.8 (VDD), Z18.8 (VDD), Z19.8 (VDD), Z20.8 (VDD); also elsewhere on the board
-5V: Z13.1 (VBB), Z14.1 (VBB), Z15.1 (VBB), Z16.1 (VBB), Z17.1 (VBB), Z18.1 (VBB), Z19.1 (VBB), Z20.1 (VBB); also elsewhere on the board
/A0: Z35.2 (I0a); also elsewhere on the board
/A1: Z35.5 (I0b); also elsewhere on the board
/A2: Z35.11 (I0c); also elsewhere on the board
/A3: Z35.14 (I0d); also elsewhere on the board
/A4: Z51.2 (I0a); also elsewhere on the board
/A5: Z51.5 (I0b); also elsewhere on the board
/A6: Z51.11 (I0c), Z71.13; also elsewhere on the board
/A7: Z35.6 (I1b); also elsewhere on the board
/A8: Z35.10 (I1c); also elsewhere on the board
/A9: Z35.13 (I1d); also elsewhere on the board
/A10: Z51.3 (I1a); also elsewhere on the board
/A11: Z51.6 (I1b); also elsewhere on the board
/A12: Z51.10 (I1c); also elsewhere on the board
/A13: Z71.14; also elsewhere on the board
/Address Decoder/~RAM: Z71.4, Z71.10; also elsewhere on the board
/Address Decoder/~RAS: Z68.14; also elsewhere on the board
/CPU Gating/MUX: Z35.1 (S), Z51.1 (S); also elsewhere on the board
/CPU Gating/~CAS: Z67.14; also elsewhere on the board
/CPU Gating/~WR: Z13.3 (~WR), Z14.3 (~WR), Z15.3 (~WR), Z16.3 (~WR), Z17.3 (~WR), Z18.3 (~WR), Z19.3 (~WR), Z20.3 (~WR); also elsewhere on the board
/D0: Z17.2 (IN); also elsewhere on the board
/D1: Z16.2 (IN); also elsewhere on the board
/D2: Z18.2 (IN); also elsewhere on the board
/D3: Z19.2 (IN); also elsewhere on the board
/D4: Z15.2 (IN); also elsewhere on the board
/D5: Z20.2 (IN); also elsewhere on the board
/D6: Z14.2 (IN); also elsewhere on the board
/D7: Z13.2 (IN); also elsewhere on the board
/RAM-ROM Interface/ROMD0: Z17.14 (OUT); also elsewhere on the board
/RAM-ROM Interface/ROMD1: Z16.14 (OUT); also elsewhere on the board
/RAM-ROM Interface/ROMD2: Z18.14 (OUT); also elsewhere on the board
/RAM-ROM Interface/ROMD3: Z19.14 (OUT); also elsewhere on the board
/RAM-ROM Interface/ROMD4: Z15.14 (OUT); also elsewhere on the board
/RAM-ROM Interface/ROMD5: Z20.14 (OUT); also elsewhere on the board
/RAM-ROM Interface/ROMD6: Z14.14 (OUT); also elsewhere on the board
/RAM-ROM Interface/ROMD7: Z13.14 (OUT); also elsewhere on the board
GND: Z13.16 (VSS), Z14.16 (VSS), Z15.16 (VSS), Z16.16 (VSS), Z17.16 (VSS), Z18.16 (VSS), Z19.16 (VSS), Z20.16 (VSS), Z35.8 (GND), Z35.15 (E), Z51.8 (GND), Z51.15 (E), Z67.12, Z68.12, Z68.15, Z71.9; also elsewhere on the board
unnamed: Z13.5 (A0), Z14.5 (A0), Z15.5 (A0), Z16.5 (A0), Z17.5 (A0), Z18.5 (A0), Z19.5 (A0), Z20.5 (A0), Z35.4 (Za)
unnamed: Z13.7 (A1), Z14.7 (A1), Z15.7 (A1), Z16.7 (A1), Z17.7 (A1), Z18.7 (A1), Z19.7 (A1), Z20.7 (A1), Z35.7 (Zb)
unnamed: Z13.6 (A2), Z14.6 (A2), Z15.6 (A2), Z16.6 (A2), Z17.6 (A2), Z18.6 (A2), Z19.6 (A2), Z20.6 (A2), Z35.9 (Zc)
unnamed: Z13.12 (A3), Z14.12 (A3), Z15.12 (A3), Z16.12 (A3), Z17.12 (A3), Z18.12 (A3), Z19.12 (A3), Z20.12 (A3), Z35.12 (Zd)
unnamed: Z13.11 (A4), Z14.11 (A4), Z15.11 (A4), Z16.11 (A4), Z17.11 (A4), Z18.11 (A4), Z19.11 (A4), Z20.11 (A4), Z51.4 (Za)
unnamed: Z13.10 (A5), Z14.10 (A5), Z15.10 (A5), Z16.10 (A5), Z17.10 (A5), Z18.10 (A5), Z19.10 (A5), Z20.10 (A5), Z51.7 (Zb)
unnamed: Z13.13 (A6), Z14.13 (A6), Z15.13 (A6), Z16.13 (A6), Z17.13 (A6), Z18.13 (A6), Z19.13 (A6), Z20.13 (A6), Z71.11, Z71.12
unnamed: R57.2, Z13.15 (~CAS), Z14.15 (~CAS), Z15.15 (~CAS), Z16.15 (~CAS), Z17.15 (~CAS), Z18.15 (~CAS), Z19.15 (~CAS), Z20.15 (~CAS), Z67.13
unnamed: R60.2, Z13.4 (~RAS), Z14.4 (~RAS), Z15.4 (~RAS), Z16.4 (~RAS), Z17.4 (~RAS), Z18.4 (~RAS), Z19.4 (~RAS), Z20.4 (~RAS), Z68.13
unnamed: Z35.3 (I1a), Z71.1, Z71.2
unnamed: Z51.9 (Zc), Z71.3
unnamed: Z67.15, Z71.5, Z71.6

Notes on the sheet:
Memory Address Multiplexer
The RAM output stays in high-impedance without ~{CAS}
16k
Used to avoid Data-Out contention between ROM and RAM for 16k RAM configurations
~{CS} for 4k DRAM

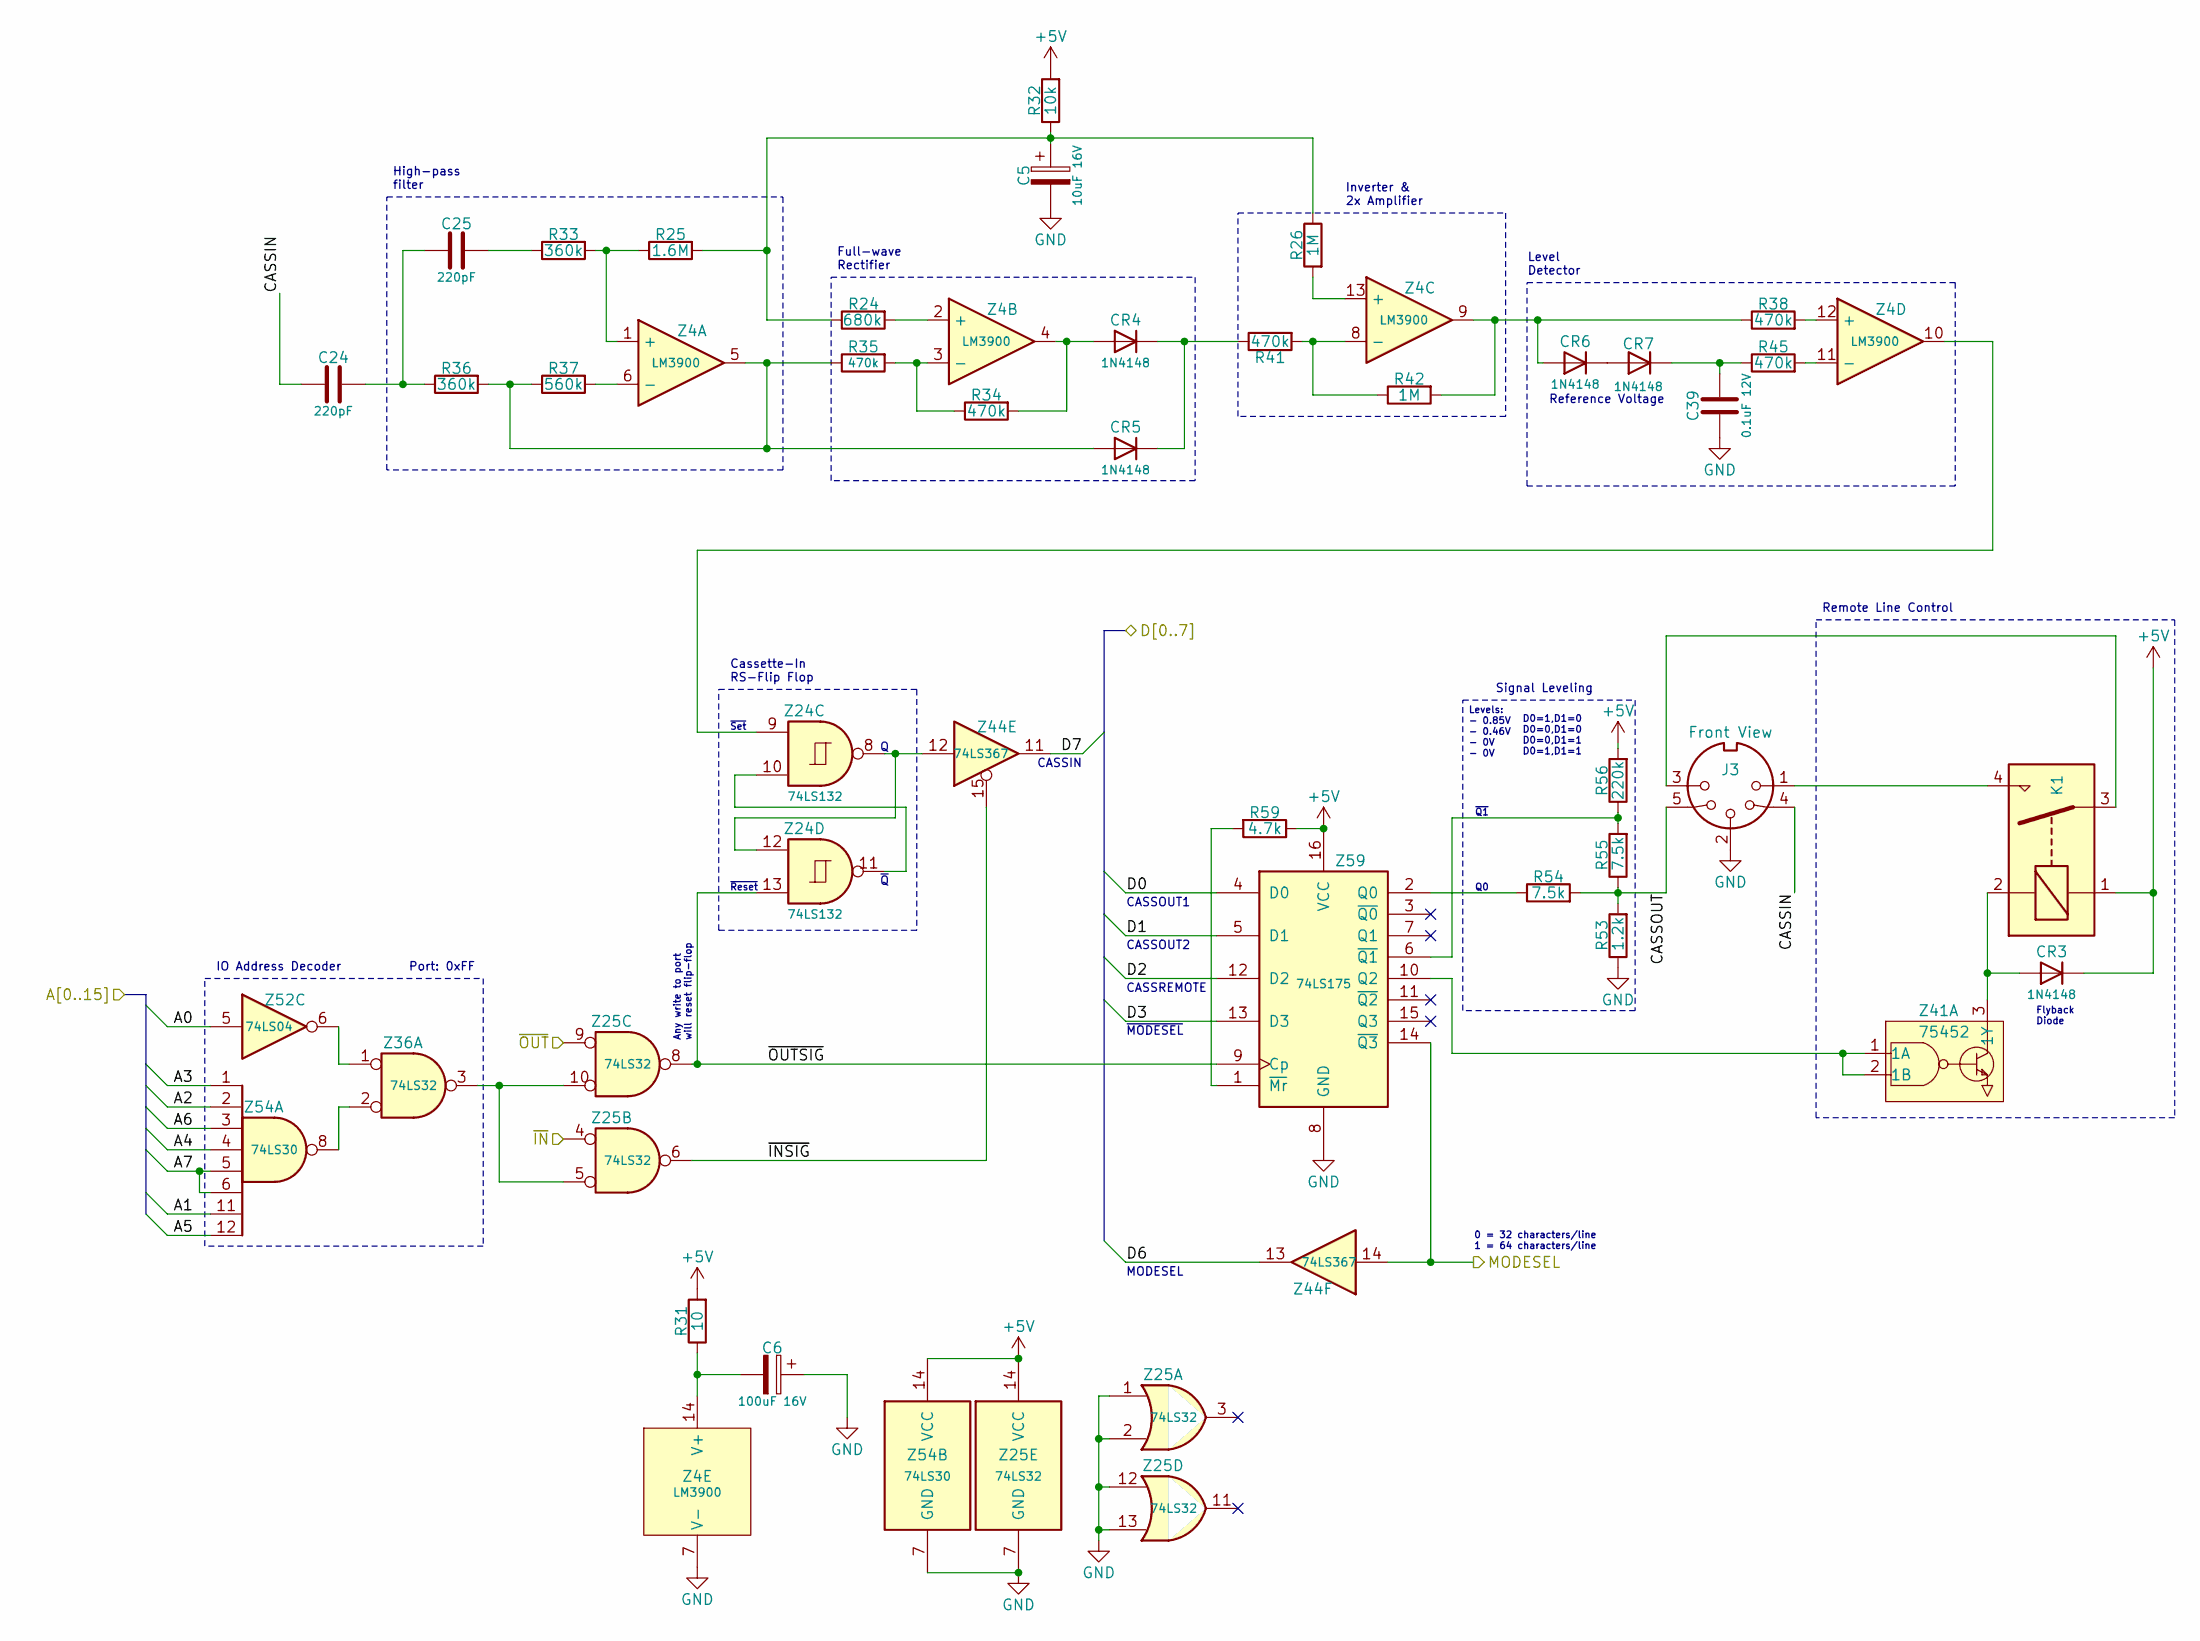
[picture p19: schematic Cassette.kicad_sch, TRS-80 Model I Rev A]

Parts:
C5: 10uF 16V; TRS80_Model_I_C_Pol_Radial_5D_2.5P
C6: 100uF 16V; TRS80_Model_I_C_Pol_Radial_10D_5P
C24, C25: 220pF; TRS80_Model_I_C_Disc_9.5L_4W_6P_Small
C39: 0.1uF 12V; TRS80_Model_I_C_Disc_9.5L_4W_6P_Small
CR3, CR4, CR5, CR6, CR7: 1N4148; TRS80_Model_I_D
J3: Front View; TRS80_Model_I_DIN5
K1: Relay_SPST-NO; TRS80_Model_I_Relay
R24: 680k; TRS80_Model_I_R_0.25W
R25: 1.6M; TRS80_Model_I_R_0.25W
R26, R42: 1M; TRS80_Model_I_R_0.25W
R31: 10; TRS80_Model_I_R_0.25W
R32: 10k; TRS80_Model_I_R_0.25W
R33, R36: 360k; TRS80_Model_I_R_0.25W
R34, R35, R38, R41, R45: 470k; TRS80_Model_I_R_0.25W
R37: 560k; TRS80_Model_I_R_0.25W
R53: 1.2k; TRS80_Model_I_R_0.25W
R54, R55: 7.5k; TRS80_Model_I_R_0.25W
R56: 220k; TRS80_Model_I_R_0.25W
R59: 4.7k; TRS80_Model_I_R_0.25W
Z4: LM3900; TRS80_Model_I_DIP14
Z24: 74LS132; TRS80_Model_I_DIP14
Z25, Z36: 74LS32; TRS80_Model_I_DIP14
Z41: 75452; TRS80_Model_I_DIP8
Z44: 74LS367; TRS80_Model_I_DIP16
Z52: 74LS04; TRS80_Model_I_DIP14
Z54: 74LS30; TRS80_Model_I_DIP14
Z59: 74LS175; TRS80_Model_I_DIP16

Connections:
+5V: CR3.1 (K), K1.1, R31.2, R32.2, R56.2, R59.1, Z25.14 (VCC), Z54.14 (VCC), Z59.16 (VCC); also elsewhere on the board
/A0: Z52.5; also elsewhere on the board
/A1: Z54.11; also elsewhere on the board
/A2: Z54.2; also elsewhere on the board
/A3: Z54.1; also elsewhere on the board
/A4: Z54.4; also elsewhere on the board
/A5: Z54.12; also elsewhere on the board
/A6: Z54.3; also elsewhere on the board
/A7: Z54.5, Z54.6; also elsewhere on the board
/CPU Gating/~IN: Z25.4; also elsewhere on the board
/CPU Gating/~OUT: Z25.9; also elsewhere on the board
/Cassette Interface/CASSIN: C24.1, J3.4
/Cassette Interface/CASSOUT: J3.5, R53.2, R54.2, R55.1
/Cassette Interface/MODESEL: Z44.14, Z59.14 (~Q3); also elsewhere on the board
/Cassette Interface/~INSIG: Z25.6, Z44.15
/Cassette Interface/~OUTSIG: Z24.13, Z25.8, Z59.9 (Cp)
/D0: Z59.4 (D0); also elsewhere on the board
/D1: Z59.5 (D1); also elsewhere on the board
/D2: Z59.12 (D2); also elsewhere on the board
/D3: Z59.13 (D3); also elsewhere on the board
/D6: Z44.13; also elsewhere on the board
/D7: Z44.11; also elsewhere on the board
GND: C5.2, C6.1, C39.1, J3.2, R53.1, Z4.7 (V-), Z25.1, Z25.2, Z25.7 (GND), Z25.12, Z25.13, Z54.7 (GND), Z59.8 (GND); also elsewhere on the board
unnamed: C5.1, R24.1, R25.2, R26.1, R32.1
unnamed: C24.2, C25.1, R36.1
unnamed: C25.2, R33.1
unnamed: CR3.2 (A), K1.2, Z41.3 (1Y)
unnamed: CR4.2 (A), R34.2, Z4.4
unnamed: CR4.1 (K), CR5.1 (K), R41.1
unnamed: CR5.2 (A), R35.1, R36.2, R37.1, Z4.5
unnamed: CR6.2 (A), R38.1, R42.2, Z4.9
unnamed: CR6.1 (K), CR7.2 (A)
unnamed: C39.2, CR7.1 (K), R45.1
unnamed: J3.1, K1.4
unnamed: J3.3, K1.3
unnamed: R25.1, R33.2, Z4.1 (+)
unnamed: R37.2, Z4.6 (-)
unnamed: R24.2, Z4.2 (+)
unnamed: R34.1, R35.2, Z4.3 (-)
unnamed: R26.2, Z4.13 (+)
unnamed: R41.2, R42.1, Z4.8 (-)
unnamed: R38.2, Z4.12 (+)
unnamed: R45.2, Z4.11 (-)
unnamed: C6.2, R31.1, Z4.14 (V+)
unnamed: Z4.10, Z24.9
unnamed: Z24.10, Z24.11
unnamed: Z24.8, Z24.12, Z44.12
unnamed: Z25.5, Z25.10, Z36.3
unnamed: Z36.1, Z52.6
unnamed: Z36.2, Z54.8
unnamed: Z41.1 (1A), Z41.2 (1B), Z59.10 (Q2)
unnamed: R54.1, Z59.2 (Q0)
unnamed: R59.2, Z59.1 (~Mr)
unnamed: R55.2, R56.1, Z59.6 (~Q1)

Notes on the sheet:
~{MODESEL}
0 = 32 characters/line 1 = 64 characters/line
Full-wave Rectifier
Level Detector
High-pass filter
Reference Voltage
Any write to port will reset flip-flop
IO Address Decoder
CASSREMOTE
Remote Line Control
Port: 0xFF
~{Q}
CASSOUT1
Flyback Diode
Signal Leveling
CASSOUT2
CASSIN
MODESEL
Cassette-In RS-Flip Flop
~{Q1}
Levels: - 0.85V - 0.46V - 0V - 0V
Inverter & 2x Amplifier
~{Reset}
~{Set}
D0=1,D1=0 D0=0,D1=0 D0=0,D1=1 D0=1,D1=1

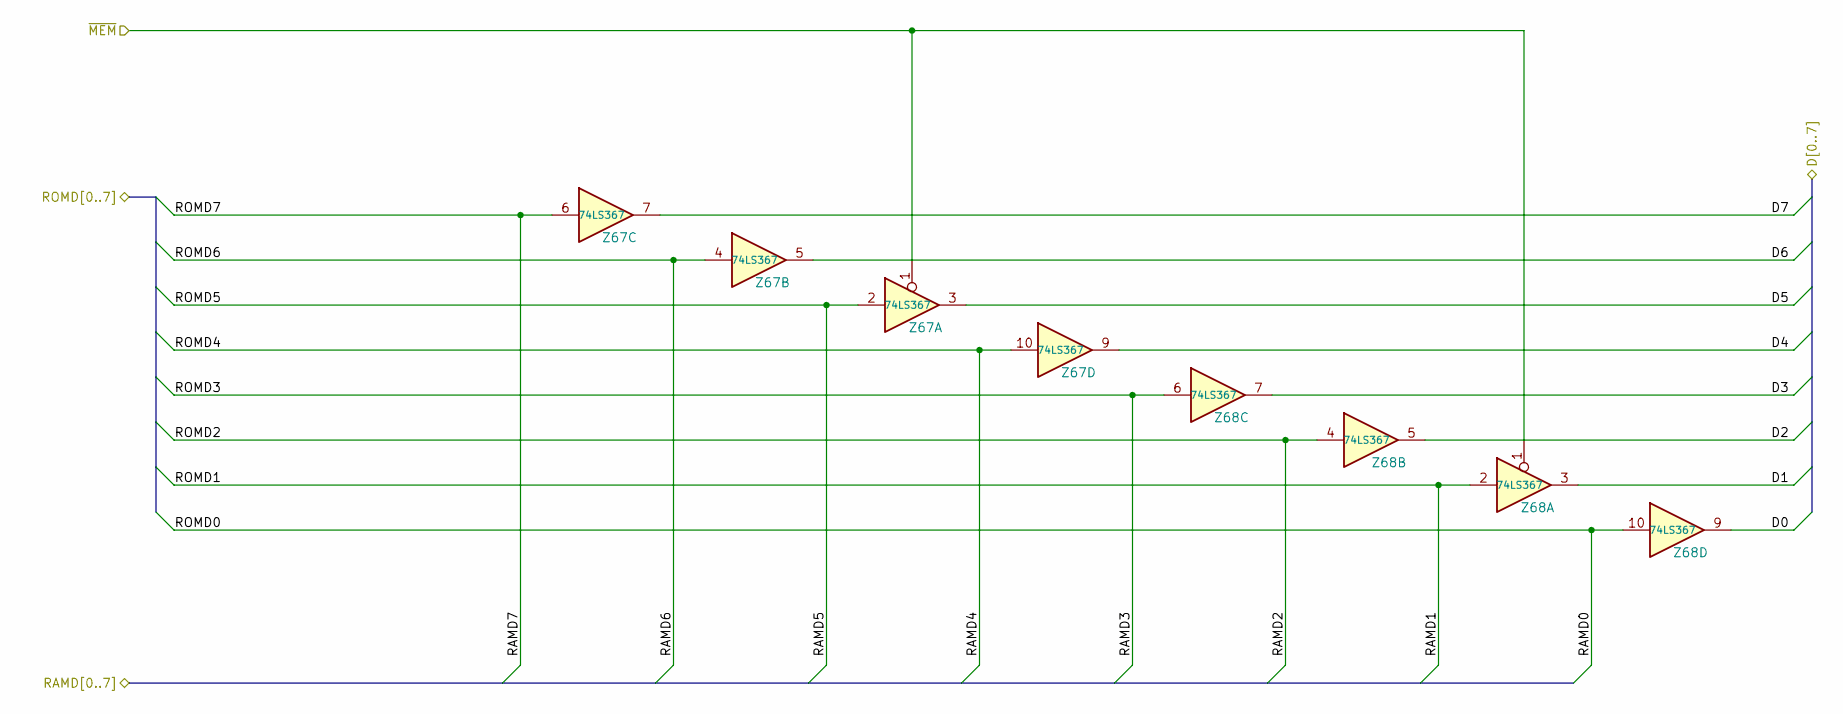
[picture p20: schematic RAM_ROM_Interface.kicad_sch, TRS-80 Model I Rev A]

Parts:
Z67, Z68: 74LS367; TRS80_Model_I_DIP16

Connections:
/Address Decoder/~MEM: Z67.1, Z68.1; also elsewhere on the board
/D0: Z68.9; also elsewhere on the board
/D1: Z68.3; also elsewhere on the board
/D2: Z68.5; also elsewhere on the board
/D3: Z68.7; also elsewhere on the board
/D4: Z67.9; also elsewhere on the board
/D5: Z67.3; also elsewhere on the board
/D6: Z67.5; also elsewhere on the board
/D7: Z67.7; also elsewhere on the board
/RAM-ROM Interface/ROMD0: Z68.10; also elsewhere on the board
/RAM-ROM Interface/ROMD1: Z68.2; also elsewhere on the board
/RAM-ROM Interface/ROMD2: Z68.4; also elsewhere on the board
/RAM-ROM Interface/ROMD3: Z68.6; also elsewhere on the board
/RAM-ROM Interface/ROMD4: Z67.10; also elsewhere on the board
/RAM-ROM Interface/ROMD5: Z67.2; also elsewhere on the board
/RAM-ROM Interface/ROMD6: Z67.4; also elsewhere on the board
/RAM-ROM Interface/ROMD7: Z67.6; also elsewhere on the board

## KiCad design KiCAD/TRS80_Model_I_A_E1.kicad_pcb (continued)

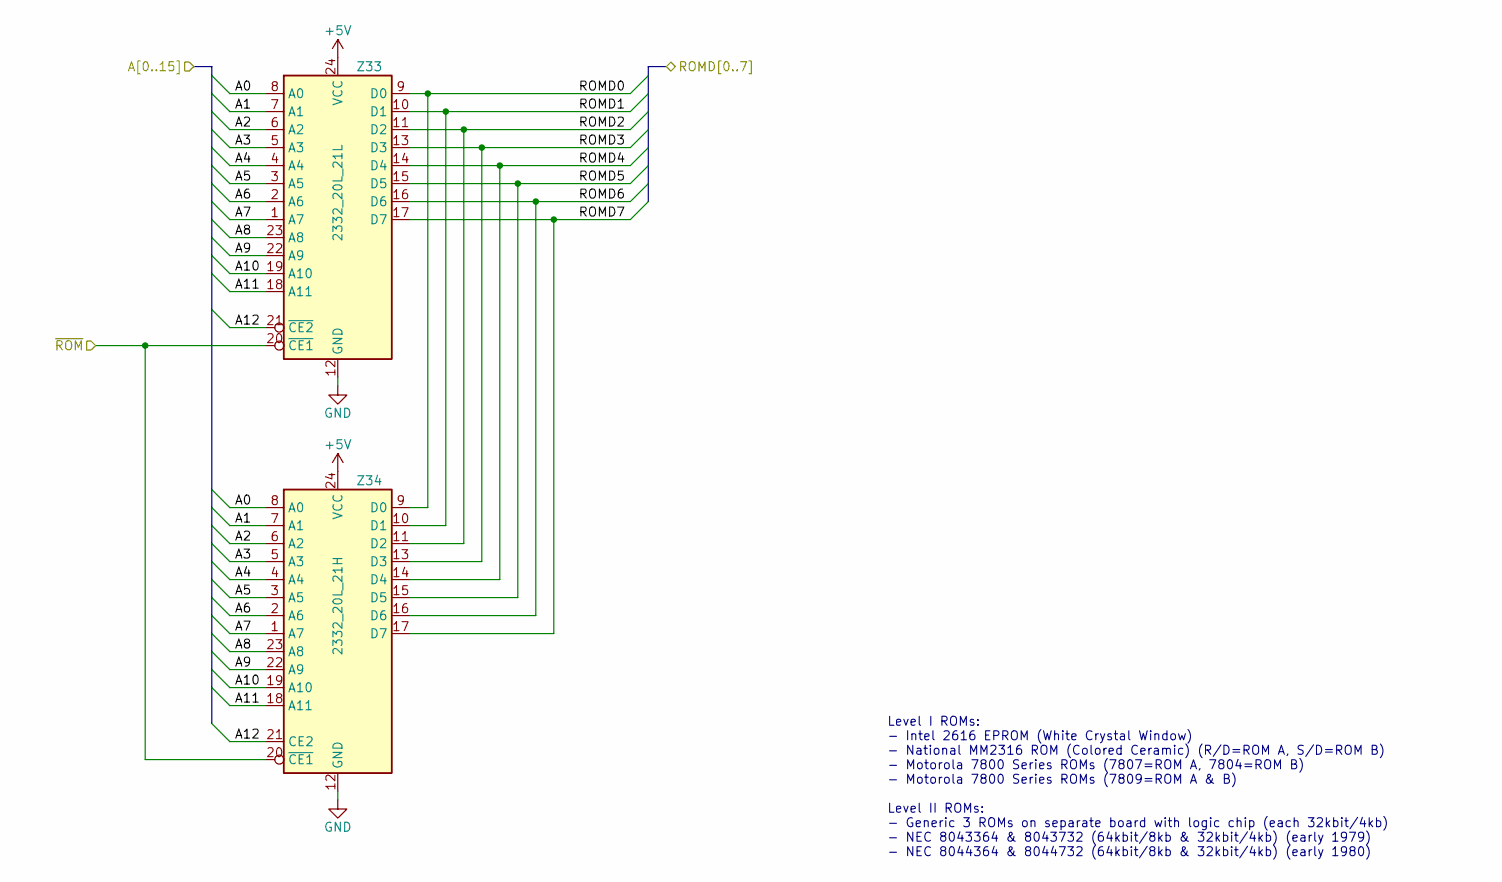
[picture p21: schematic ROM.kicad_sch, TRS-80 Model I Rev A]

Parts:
Z33: 2332_20L_21L; TRS80_Model_I_DIP24
Z34: 2332_20L_21H; TRS80_Model_I_DIP24

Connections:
+5V: Z33.24 (VCC), Z34.24 (VCC); also elsewhere on the board
/A0: Z33.8 (A0), Z34.8 (A0); also elsewhere on the board
/A1: Z33.7 (A1), Z34.7 (A1); also elsewhere on the board
/A2: Z33.6 (A2), Z34.6 (A2); also elsewhere on the board
/A3: Z33.5 (A3), Z34.5 (A3); also elsewhere on the board
/A4: Z33.4 (A4), Z34.4 (A4); also elsewhere on the board
/A5: Z33.3 (A5), Z34.3 (A5); also elsewhere on the board
/A6: Z33.2 (A6), Z34.2 (A6); also elsewhere on the board
/A7: Z33.1 (A7), Z34.1 (A7); also elsewhere on the board
/A8: Z33.23 (A8), Z34.23 (A8); also elsewhere on the board
/A9: Z33.22 (A9), Z34.22 (A9); also elsewhere on the board
/A10: Z33.19 (A10), Z34.19 (A10); also elsewhere on the board
/A11: Z33.18 (A11), Z34.18 (A11); also elsewhere on the board
/A12: Z33.21 (~CE2), Z34.21 (CE2); also elsewhere on the board
/Address Decoder/~ROM: Z33.20 (~CE1), Z34.20 (~CE1); also elsewhere on the board
/RAM-ROM Interface/ROMD0: Z33.9 (D0), Z34.9 (D0); also elsewhere on the board
/RAM-ROM Interface/ROMD1: Z33.10 (D1), Z34.10 (D1); also elsewhere on the board
/RAM-ROM Interface/ROMD2: Z33.11 (D2), Z34.11 (D2); also elsewhere on the board
/RAM-ROM Interface/ROMD3: Z33.13 (D3), Z34.13 (D3); also elsewhere on the board
/RAM-ROM Interface/ROMD4: Z33.14 (D4), Z34.14 (D4); also elsewhere on the board
/RAM-ROM Interface/ROMD5: Z33.15 (D5), Z34.15 (D5); also elsewhere on the board
/RAM-ROM Interface/ROMD6: Z33.16 (D6), Z34.16 (D6); also elsewhere on the board
/RAM-ROM Interface/ROMD7: Z33.17 (D7), Z34.17 (D7); also elsewhere on the board
GND: Z33.12 (GND), Z34.12 (GND); also elsewhere on the board

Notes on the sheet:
Level I ROMs: - Intel 2616 EPROM (White Crystal Window) - National MM2316 ROM (Colored Ceramic) (R/D=ROM A, S/D=ROM B) - Motorola 7800 Series ROMs (7807=ROM A, 7804=ROM B) - Motorola 7800 Series ROMs (7809=ROM A & B) Level II ROMs: - Generic 3 ROMs on separate board with logic chip (each 32kbit/4kb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

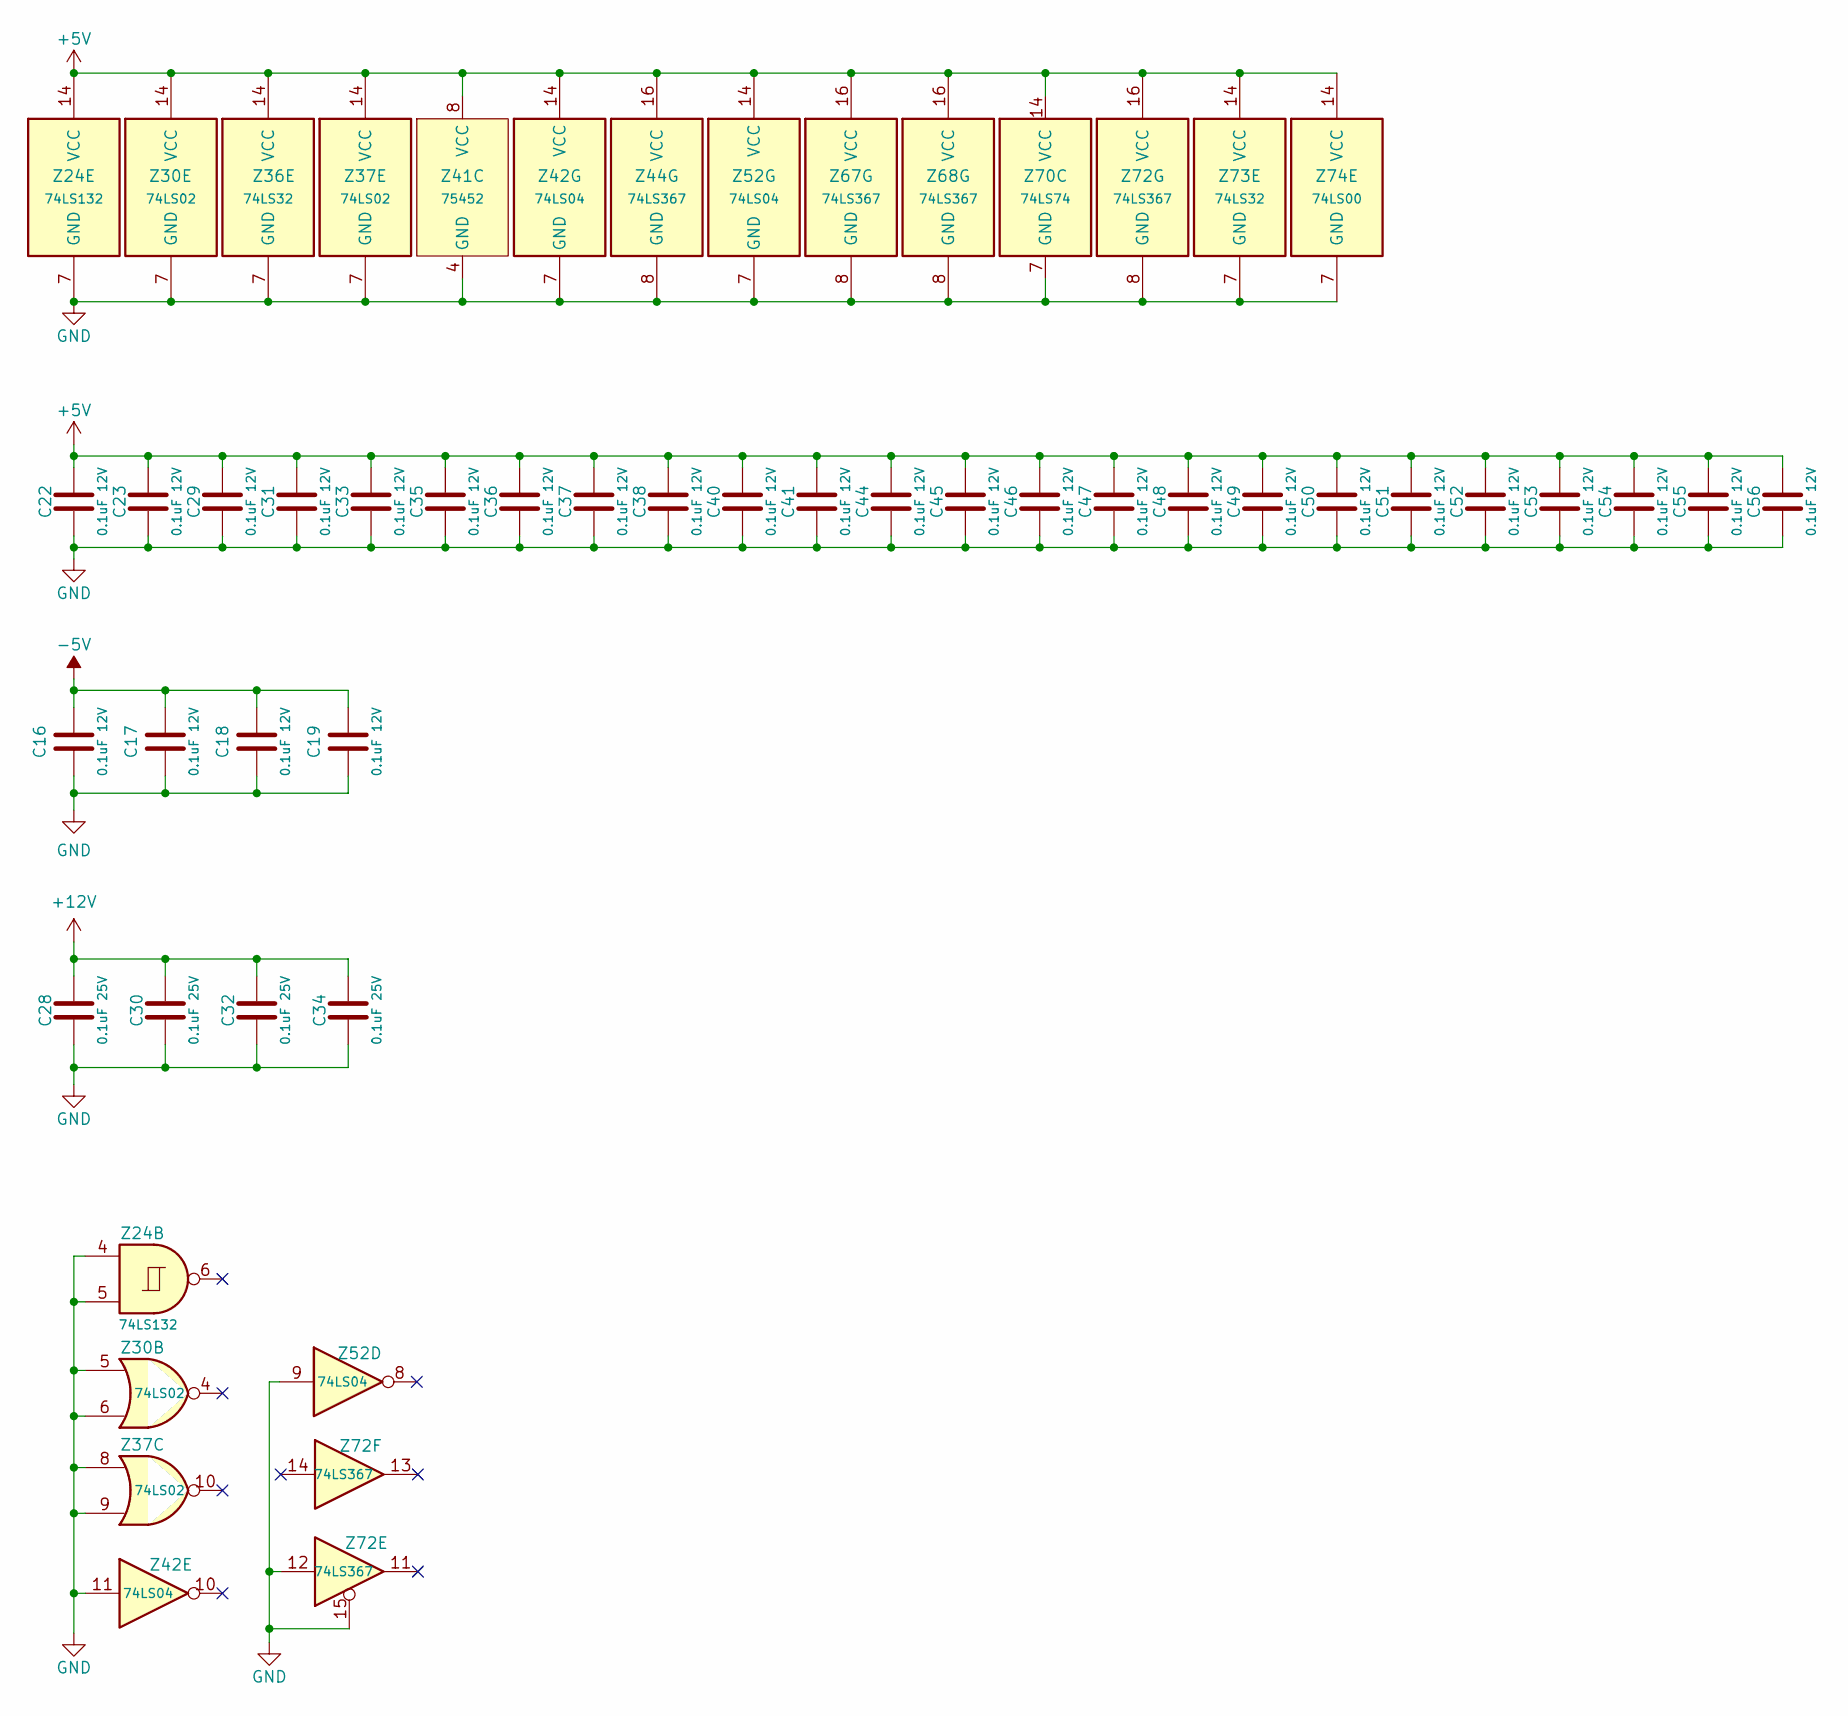
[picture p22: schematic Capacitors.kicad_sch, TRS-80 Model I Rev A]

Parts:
C16, C17, C18, C19, C22, C23, C29, C31, C33, C35, C36, C37, C38, C40, C41, C44, C45, C46, C47, C48, C49, C50, C51, C52, C53, C54, C55, C56: 0.1uF 12V; TRS80_Model_I_C_Disc_9.5L_4W_6P_Small
C28, C30, C32, C34: 0.1uF 25V; TRS80_Model_I_C_Disc_18.5L_4W_8.5P_Large
Z24: 74LS132; TRS80_Model_I_DIP14
Z30, Z37: 74LS02; TRS80_Model_I_DIP14
Z36, Z73: 74LS32; TRS80_Model_I_DIP14
Z41: 75452; TRS80_Model_I_DIP8
Z42, Z52: 74LS04; TRS80_Model_I_DIP14
Z44, Z67, Z68, Z72: 74LS367; TRS80_Model_I_DIP16
Z70: 74LS74; TRS80_Model_I_DIP14
Z74: 74LS00; TRS80_Model_I_DIP14

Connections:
+5V: C22.1, C23.1, C29.1, C31.1, C33.1, C35.1, C36.1, C37.1, C38.1, C40.1, C41.1, C44.1, C45.1, C46.1, C47.1, C48.1, C49.1, C50.1, C51.1, C52.1, C53.1, C54.1, C55.1, C56.1, Z24.14 (VCC), Z30.14 (VCC), Z36.14 (VCC), Z37.14 (VCC), Z41.8 (VCC), Z42.14 (VCC), Z44.16 (VCC), Z52.14 (VCC), Z67.16 (VCC), Z68.16 (VCC), Z70.14 (VCC), Z72.16 (VCC), Z73.14 (VCC), Z74.14 (VCC); also elsewhere on the board
+12V: C28.1, C30.1, C32.1, C34.1; also elsewhere on the board
-5V: C16.1, C17.1, C18.1, C19.1; also elsewhere on the board
/Cassette Interface/MODESEL: Z44.14; also elsewhere on the board
/D6: Z44.13; also elsewhere on the board
GND: C16.2, C17.2, C18.2, C19.2, C22.2, C23.2, C28.2, C29.2, C30.2, C31.2, C32.2, C33.2, C34.2, C35.2, C36.2, C37.2, C38.2, C40.2, C41.2, C44.2, C45.2, C46.2, C47.2, C48.2, C49.2, C50.2, C51.2, C52.2, C53.2, C54.2, C55.2, C56.2, Z24.4, Z24.5, Z24.7 (GND), Z30.5, Z30.6, Z30.7 (GND), Z36.7 (GND), Z37.7 (GND), Z37.8, Z37.9, Z41.4 (GND), Z42.7 (GND), Z42.11, Z44.8 (GND), Z52.7 (GND), Z52.9, Z67.8 (GND), Z68.8 (GND), Z70.7 (GND), Z72.8 (GND), Z72.12, Z72.15, Z73.7 (GND), Z74.7 (GND); also elsewhere on the board

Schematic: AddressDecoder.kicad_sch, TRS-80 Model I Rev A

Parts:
R48, R61, R62: 4.7k; TRS80_Model_I_R_0.25W
Z3: TRS80_Model_I_DIP14
Z21: 74LS156; TRS80_Model_I_DIP16
Z36, Z73: 74LS32; TRS80_Model_I_DIP14
Z37: 74LS02; TRS80_Model_I_DIP14
Z52: 74LS04; TRS80_Model_I_DIP14
Z74: 74LS00; TRS80_Model_I_DIP14

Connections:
+5V: R48.2, R61.2, R62.2, Z21.16 (VCC); also elsewhere on the board
/A10: Z36.13, Z52.1; also elsewhere on the board
/A11: Z37.5, Z37.6; also elsewhere on the board
/A12: Z21.13 (A0); also elsewhere on the board
/A13: Z21.3 (A1); also elsewhere on the board
/A14: Z21.1 (Ea1), Z21.15 (Eb2); also elsewhere on the board
/A15: Z73.4; also elsewhere on the board
/Address Decoder/~KYBD: Z36.11; also elsewhere on the board
/Address Decoder/~MEM: Z74.3; also elsewhere on the board
/Address Decoder/~RAM: R62.1, Z3.10, Z3.11, Z3.12, Z21.7 (Q0a), Z74.10; also elsewhere on the board
/Address Decoder/~RAS: Z73.5; also elsewhere on the board
/Address Decoder/~RD: Z52.13; also elsewhere on the board
/Address Decoder/~ROM: R61.1, Z3.6, Z3.7, Z21.9 (Q0b), Z74.9; also elsewhere on the board
/Address Decoder/~VID: Z36.8; also elsewhere on the board
GND: Z21.8 (GND), Z73.10, Z73.12, Z74.12, Z74.13; also elsewhere on the board
unnamed: Z21.2 (Ea2), Z21.14 (Eb1), Z73.6
unnamed: Z3.3, Z21.6 (Q1a)
unnamed: Z3.8, Z21.10 (Q1b)
unnamed: Z3.4, Z21.5 (Q2a)
unnamed: Z3.9, Z21.11 (Q2b)
unnamed: Z3.5, Z21.4 (Q3a)
unnamed: R48.1, Z21.12 (Q3b), Z36.4
unnamed: Z36.5, Z37.4
unnamed: Z36.9, Z52.2
unnamed: Z36.6, Z36.10, Z36.12
unnamed: Z52.12, Z74.1
unnamed: Z74.2, Z74.8

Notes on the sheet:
38xx..3Bxx
5xxx
4xxx
0001
0000
0111
RAS=0 && A15=0
7xxx
2xxx
0100
0xxx, 1xxx, 2xxx
0011
4xxx..7xxx
0010
0101
3Cxx..3Fxx
0xxx
A14=0
A14=1
0110
6xxx
1xxx
3xxx

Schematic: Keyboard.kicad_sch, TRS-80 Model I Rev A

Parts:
J100: Connection Mainboard Side; TRS80_Model_I_Keyboard_Connector

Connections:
+5V: J100.1; also elsewhere on the board
/A0: J100.5; also elsewhere on the board
/A1: J100.4; also elsewhere on the board
/A2: J100.6; also elsewhere on the board
/A3: J100.9; also elsewhere on the board
/A4: J100.2; also elsewhere on the board
/A5: J100.3; also elsewhere on the board
/A6: J100.7; also elsewhere on the board
/A7: J100.8; also elsewhere on the board
/Address Decoder/~KYBD: J100.14; also elsewhere on the board
/D0: J100.11; also elsewhere on the board
/D1: J100.16; also elsewhere on the board
/D2: J100.10; also elsewhere on the board
/D3: J100.13; also elsewhere on the board
/D4: J100.18; also elsewhere on the board
/D5: J100.12; also elsewhere on the board
/D6: J100.15; also elsewhere on the board
/D7: J100.17; also elsewhere on the board
GND: J100.19; also elsewhere on the board

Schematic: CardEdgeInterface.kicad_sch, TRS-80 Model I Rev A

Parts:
J4: Edge Connector; TRS80_Model_I_Edge_Connector
R50, R51, R58: 4.7k; TRS80_Model_I_R_0.25W

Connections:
+5V: J4.39, R50.1, R51.1, R58.1; also elsewhere on the board
/A0: J4.25; also elsewhere on the board
/A1: J4.27; also elsewhere on the board
/A2: J4.40; also elsewhere on the board
/A3: J4.34; also elsewhere on the board
/A4: J4.31; also elsewhere on the board
/A5: J4.35; also elsewhere on the board
/A6: J4.38; also elsewhere on the board
/A7: J4.36; also elsewhere on the board
/A8: J4.11; also elsewhere on the board
/A9: J4.17; also elsewhere on the board
/A10: J4.4; also elsewhere on the board
/A11: J4.9; also elsewhere on the board
/A12: J4.5; also elsewhere on the board
/A13: J4.6; also elsewhere on the board
/A14: J4.10; also elsewhere on the board
/A15: J4.7; also elsewhere on the board
/Address Decoder/~RAS: J4.1; also elsewhere on the board
/Address Decoder/~RD: J4.15; also elsewhere on the board
/CPU Gating/MUX: J4.16; also elsewhere on the board
/CPU Gating/~CAS: J4.3; also elsewhere on the board
/CPU Gating/~IN: J4.19; also elsewhere on the board
/CPU Gating/~OUT: J4.12; also elsewhere on the board
/CPU Gating/~TEST: J4.23, R58.2; also elsewhere on the board
/CPU Gating/~WR: J4.13; also elsewhere on the board
/CPU/~INTAK: J4.14; also elsewhere on the board
/CPU/~INT: J4.21, R50.2; also elsewhere on the board
/CPU/~SYSRES: J4.2; also elsewhere on the board
/CPU/~WAIT: J4.33, R51.2; also elsewhere on the board
/D0: J4.30; also elsewhere on the board
/D1: J4.22; also elsewhere on the board
/D2: J4.32; also elsewhere on the board
/D3: J4.26; also elsewhere on the board
/D4: J4.18; also elsewhere on the board
/D5: J4.28; also elsewhere on the board
/D6: J4.24; also elsewhere on the board
/D7: J4.20; also elsewhere on the board
GND: J4.8, J4.29, J4.37; also elsewhere on the board

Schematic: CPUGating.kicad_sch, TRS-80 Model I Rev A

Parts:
Z22, Z38, Z39, Z55, Z72, Z75, Z76: 74LS367; TRS80_Model_I_DIP16
Z52: 74LS04; TRS80_Model_I_DIP14

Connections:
+5V: Z22.16 (VCC), Z38.16 (VCC), Z39.16 (VCC), Z55.16 (VCC), Z75.16 (VCC), Z76.16 (VCC); also elsewhere on the board
/A0: Z55.11; also elsewhere on the board
/A1: Z55.13; also elsewhere on the board
/A2: Z22.11; also elsewhere on the board
/A3: Z22.13; also elsewhere on the board
/A4: Z39.7; also elsewhere on the board
/A5: Z39.9; also elsewhere on the board
/A6: Z39.5; also elsewhere on the board
/A7: Z39.11; also elsewhere on the board
/A8: Z39.3; also elsewhere on the board
/A9: Z39.13; also elsewhere on the board
/A10: Z38.3; also elsewhere on the board
/A11: Z38.13; also elsewhere on the board
/A12: Z38.5; also elsewhere on the board
/A13: Z38.7; also elsewhere on the board
/A14: Z38.11; also elsewhere on the board
/A15: Z38.9; also elsewhere on the board
/Address Decoder/~RAS: Z72.5; also elsewhere on the board
/Address Decoder/~RD: Z22.7; also elsewhere on the board
/CPU Gating/MUX: Z72.3; also elsewhere on the board
/CPU Gating/ZA0: Z55.12; also elsewhere on the board
/CPU Gating/ZA1: Z55.14; also elsewhere on the board
/CPU Gating/ZA2: Z22.12; also elsewhere on the board
/CPU Gating/ZA3: Z22.14; also elsewhere on the board
/CPU Gating/ZA4: Z39.6; also elsewhere on the board
/CPU Gating/ZA5: Z39.10; also elsewhere on the board
/CPU Gating/ZA6: Z39.4; also elsewhere on the board
/CPU Gating/ZA7: Z39.12; also elsewhere on the board
/CPU Gating/ZA8: Z39.2; also elsewhere on the board
/CPU Gating/ZA9: Z39.14; also elsewhere on the board
/CPU Gating/ZA10: Z38.2; also elsewhere on the board
/CPU Gating/ZA11: Z38.14; also elsewhere on the board
/CPU Gating/ZA12: Z38.4; also elsewhere on the board
/CPU Gating/ZA13: Z38.6; also elsewhere on the board
/CPU Gating/ZA14: Z38.12; also elsewhere on the board
/CPU Gating/ZA15: Z38.10; also elsewhere on the board
/CPU Gating/ZD0: Z76.9, Z76.12; also elsewhere on the board
/CPU Gating/ZD1: Z76.3, Z76.14; also elsewhere on the board
/CPU Gating/ZD2: Z75.14, Z76.5; also elsewhere on the board
/CPU Gating/ZD3: Z55.5, Z75.4; also elsewhere on the board
/CPU Gating/ZD4: Z55.3, Z75.6; also elsewhere on the board
/CPU Gating/ZD5: Z55.7, Z75.2; also elsewhere on the board
/CPU Gating/ZD6: Z55.9, Z75.10; also elsewhere on the board
/CPU Gating/ZD7: Z75.12, Z76.7; also elsewhere on the board
/CPU Gating/ZMUX: Z72.2; also elsewhere on the board
/CPU Gating/~CAS: Z72.9; also elsewhere on the board
/CPU Gating/~DBIN: Z55.1, Z76.1; also elsewhere on the board
/CPU Gating/~DBOUT: Z75.1, Z75.15, Z76.15; also elsewhere on the board
/CPU Gating/~IN: Z22.9; also elsewhere on the board
/CPU Gating/~OUT: Z22.3; also elsewhere on the board
/CPU Gating/~TEST: Z52.3; also elsewhere on the board
/CPU Gating/~WR: Z22.5; also elsewhere on the board
/CPU Gating/~ZCAS: Z72.10; also elsewhere on the board
/CPU Gating/~ZIN: Z22.10; also elsewhere on the board
/CPU Gating/~ZOUT: Z22.2; also elsewhere on the board
/CPU Gating/~ZRAS: Z72.4; also elsewhere on the board
/CPU Gating/~ZRD: Z22.6; also elsewhere on the board
/CPU Gating/~ZWR: Z22.4; also elsewhere on the board
/D0: Z76.10, Z76.11; also elsewhere on the board
/D1: Z76.2, Z76.13; also elsewhere on the board
/D2: Z75.13, Z76.4; also elsewhere on the board
/D3: Z55.4, Z75.5; also elsewhere on the board
/D4: Z55.2, Z75.7; also elsewhere on the board
/D5: Z55.6, Z75.3; also elsewhere on the board
/D6: Z55.10, Z75.9; also elsewhere on the board
/D7: Z75.11, Z76.6; also elsewhere on the board
GND: Z22.8 (GND), Z38.8 (GND), Z39.8 (GND), Z55.8 (GND), Z72.1, Z75.8 (GND), Z76.8 (GND); also elsewhere on the board
unnamed: Z22.1, Z22.15, Z38.1, Z38.15, Z39.1, Z39.15, Z52.4, Z55.15

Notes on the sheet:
Bi-directional Data Bus
Address Bus
Control Signals

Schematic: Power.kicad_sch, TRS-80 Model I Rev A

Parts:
C1: 220uF 16V; TRS80_Model_I_C_Pol_Axial_21L_9W_29P
C3, C14, C15: 0.01uF 24V; TRS80_Model_I_C_Disc_9.5L_4W_6P_Small
C4, C10, C11: 10uF 16V; TRS80_Model_I_C_Pol_Radial_5D_2.5P
C8: 2200uF 35V; TRS80_Model_I_C_Pol_Axial_41L_19W_48P
C9: 10000uF 16V; TRS80_Model_I_C_Pol_Axial_63L_25W_71P
C12, C13: 470pF; TRS80_Model_I_C_Disc_9.5L_4W_6P_Small
CR1: 1N4735; TRS80_Model_I_D
CR2: 1N5231; TRS80_Model_I_D
CR8: MDA202; TRS80_Model_I_D_Bridge
J1: Front View; TRS80_Model_I_DIN5
Q3: TIP29A; TRS80_Model_I_Q_Box_BCE
Q4: 2N6594; TRS80_Model_I_Q_Heatsink_Large_BEC
Q5: 2N3906; TRS80_Model_I_Q_Circle_EBC
Q6: MJE34; TRS80_Model_I_Q_Heatsink_Small_BCE
R1: 68; TRS80_Model_I_R_0.25W
R2: 2.7k; TRS80_Model_I_R_0.25W
R3: 750; TRS80_Model_I_R_0.25W
R4: 0.33; TRS80_Model_I_R_2W
R5, R10: 1k; TRS80_Model_I_R_Pot
R6, R7, R16: 1.2k; TRS80_Model_I_R_0.25W
R8: 100k; TRS80_Model_I_R_0.25W
R9, R11, R12: 3.3k; TRS80_Model_I_R_0.25W
R13: 2.2k; TRS80_Model_I_R_0.25W
R14: 12k; TRS80_Model_I_R_0.25W
R15: 1.5k; TRS80_Model_I_R_0.25W
R17: 2k; TRS80_Model_I_R_0.25W
R18: 5.6; TRS80_Model_I_R_3W
R19: 220; TRS80_Model_I_R_0.5W
S1: TRS80_Model_I_Sw_Large
Z1, Z2: LM723C; TRS80_Model_I_DIP14

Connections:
+5V: C10.1, C14.1, CR1.1 (K), R4.2, R7.1, R8.2, Z1.3 (CSEN); also elsewhere on the board
+12V: C11.1, C15.1, R13.1, R18.1, Z1.11 (VC), Z1.12 (V+), Z2.3 (CSEN); also elsewhere on the board
-5V: C3.1, C4.2, CR2.2 (A), R19.1; also elsewhere on the board
GND: C1.1, C3.2, C4.1, C8.2, C9.2, C10.2, C11.2, C14.2, C15.2, CR1.2 (A), CR2.1 (K), J1.4, R11.2, R12.2, R14.2, Z1.7 (V-), Z2.7 (V-); also elsewhere on the board
unnamed: C1.2, R19.2, S1.10
unnamed: CR8.1 (+), S1.4, S1.5, S1.8, S1.9
unnamed: CR8.4 (-), S1.11, S1.12
unnamed: CR8.2, J1.1
unnamed: CR8.3, J1.3
unnamed: J1.2, S1.1, S1.2
unnamed: Q3.1 (B), R2.1, Z1.10 (Vout)
unnamed: Q3.2 (C), Q4.1 (B), R1.2
unnamed: Q3.3 (E), Q4.3 (C), R2.2, R3.1, R4.1
unnamed: C9.1, Q4.2 (E), R1.1, S1.6, S1.7
unnamed: Q5.2 (B), R8.1
unnamed: Q5.3 (C), R9.2
unnamed: Q5.1 (E), R5.2, Z1.5 (+)
unnamed: Q6.1 (B), R16.2, Z2.11 (VC)
unnamed: Q6.2 (C), R17.1, R18.2, Z2.10 (Vout)
unnamed: C8.1, Q6.3 (E), R16.1, S1.3, Z2.12 (V+)
unnamed: R5.1, R6.1
unnamed: R10.1, R12.1
unnamed: R10.3, R13.2
unnamed: R5.3, R11.1
unnamed: C12.1, R7.2, Z1.4 (-)
unnamed: C12.2, Z1.13 (FC)
unnamed: R3.2, R9.1, Z1.2 (ILIM)
unnamed: R6.2, Z1.6 (VREF)
unnamed: R15.2, Z2.5 (+)
unnamed: C13.2, R10.2, Z2.4 (-)
unnamed: C13.1, Z2.13 (FC)
unnamed: R14.1, R17.2, Z2.2 (ILIM)
unnamed: R15.1, Z2.6 (VREF)

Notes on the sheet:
12V-20V AC 1A
0.5W
14V-20V DC 350mA

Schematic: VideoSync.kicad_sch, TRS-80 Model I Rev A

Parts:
C20: 750pF; TRS80_Model_I_C_Disc_9.5L_4W_6P_Small
C21: 330pF; TRS80_Model_I_C_Disc_9.5L_4W_6P_Small
C26: 0.047uF; TRS80_Model_I_C_Box_11L_5W_6P_Large
C27: 0.022uF; TRS80_Model_I_C_Box_7.5L_5W_4.5P_Small
R20, R21: 100k; TRS80_Model_I_R_Pot
R43, R44: 10k; TRS80_Model_I_R_0.25W
Z5: 74C00; TRS80_Model_I_DIP14
Z6, Z57: 74C04; TRS80_Model_I_DIP14

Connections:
+5V: Z5.14 (VCC), Z6.14 (VCC), Z57.14 (VCC); also elsewhere on the board
/Video/Video Counter/HDRV: Z6.13; also elsewhere on the board
/Video/Video Counter/VDRV: Z57.1; also elsewhere on the board
/Video/Video Mixer/SYNC: Z5.8; also elsewhere on the board
GND: R43.2, R44.1, Z5.7 (GND), Z6.7 (GND), Z57.5, Z57.7 (GND), Z57.9, Z57.11, Z57.13; also elsewhere on the board
unnamed: C20.1, R43.1, Z5.2, Z5.13
unnamed: C20.2, C21.1, Z6.6
unnamed: C21.2, R20.1, Z6.3
unnamed: C26.1, R21.2, Z6.11
unnamed: C26.2, C27.1, Z6.8
unnamed: C27.2, R44.2, Z5.1, Z5.5
unnamed: R20.2, Z6.2
unnamed: R21.1, Z57.4
unnamed: Z5.6, Z5.9
unnamed: Z5.10, Z5.11
unnamed: Z5.3, Z5.4, Z5.12
unnamed: Z6.1, Z6.12
unnamed: Z6.4, Z6.5
unnamed: Z6.9, Z6.10
unnamed: Z57.2, Z57.3

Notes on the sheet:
Amplifier
Sync Offset
H-Sync
V-Sync Offset Capacitor
V-Sync
Inv-Sync
H-Sync Offset Capacitor
Sync Pulse Length
V-Sync Length
V-Sync Offset Resistor
H-Sync Length
Combine Sync Signals
H-Sync Offset Resistor

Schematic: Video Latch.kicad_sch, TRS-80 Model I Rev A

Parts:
R39: 4.7k; TRS80_Model_I_R_0.25W
Z7: 74LS74; TRS80_Model_I_DIP14
Z27: 74LS175; TRS80_Model_I_DIP16
Z28: 74LS174; TRS80_Model_I_DIP16
Z30: 74LS02; TRS80_Model_I_DIP14
Z42: 74LS04; TRS80_Model_I_DIP14

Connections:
+5V: R39.2, Z7.14 (VCC), Z27.16 (VCC), Z28.16 (VCC); also elsewhere on the board
/Address Decoder/~VID: Z7.4 (~S); also elsewhere on the board
/Video/Video Counter/HDRV: Z30.8; also elsewhere on the board
/Video/Video Counter/L3: Z27.12 (D2); also elsewhere on the board
/Video/Video Counter/VDRV: Z30.9; also elsewhere on the board
/Video/Video Counter/~LATCH: Z7.3 (C), Z27.9 (Cp), Z28.9 (Cp); also elsewhere on the board
/Video/Video Generator/GRAPHICS: Z27.3 (~Q0); also elsewhere on the board
/Video/Video Generator/LB0: Z28.15 (Q5); also elsewhere on the board
/Video/Video Generator/LB1: Z28.12 (Q4); also elsewhere on the board
/Video/Video Generator/LB2: Z28.2 (Q0); also elsewhere on the board
/Video/Video Generator/LB3: Z28.7 (Q2); also elsewhere on the board
/Video/Video Generator/LB4: Z28.5 (Q1); also elsewhere on the board
/Video/Video Generator/LB5: Z28.10 (Q3); also elsewhere on the board
/Video/Video Generator/LB6: Z27.15 (Q3); also elsewhere on the board
/Video/Video Generator/~BLANK: Z27.7 (Q1); also elsewhere on the board
/Video/Video Generator/~CHARGAP: Z27.11 (~Q2); also elsewhere on the board
/Video/Video Generator/~GRAPHICS: Z27.2 (Q0); also elsewhere on the board
/Video/Video Latch/VD0: Z28.14 (D5); also elsewhere on the board
/Video/Video Latch/VD1: Z28.13 (D4); also elsewhere on the board
/Video/Video Latch/VD2: Z28.3 (D0); also elsewhere on the board
/Video/Video Latch/VD3: Z28.6 (D2); also elsewhere on the board
/Video/Video Latch/VD4: Z28.4 (D1); also elsewhere on the board
/Video/Video Latch/VD5: Z28.11 (D3); also elsewhere on the board
/Video/Video Latch/VD6: Z27.13 (D3); also elsewhere on the board
/Video/Video Latch/VD7: Z42.13; also elsewhere on the board
/Video/Video Latch/~VCLR: Z7.6 (~Q), Z27.1 (~Mr), Z28.1 (~Mr)
GND: Z7.2 (D), Z7.7 (GND), Z7.10 (~S), Z7.11 (C), Z7.12 (D), Z7.13 (~R), Z27.8 (GND), Z28.8 (GND); also elsewhere on the board
unnamed: R39.1, Z7.1 (~R)
unnamed: Z27.4 (D0), Z42.12
unnamed: Z27.5 (D1), Z30.10

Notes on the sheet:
CHARGAP
GRAPHICS
Clear when CPU drives
~{BLANK}
~{GRAPHICS}

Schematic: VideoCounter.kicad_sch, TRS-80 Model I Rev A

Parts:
Z12, Z32, Z50, Z65: 74LS93; TRS80_Model_I_DIP14
Z24: 74LS132; TRS80_Model_I_DIP14
Z43: 74LS157; TRS80_Model_I_DIP16
Z58: 74LS92; TRS80_Model_I_DIP14
Z66: 74LS11; TRS80_Model_I_DIP14
Z70: 74LS74; TRS80_Model_I_DIP14

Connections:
+5V: Z12.5 (VCC), Z32.5 (VCC), Z43.16 (VCC), Z50.5 (VCC), Z58.5 (VCC), Z65.5 (VCC), Z66.14 (VCC); also elsewhere on the board
/CPU/CLK: Z43.3 (I1a), Z70.11 (C); also elsewhere on the board
/CPU/HI: Z70.10 (~S), Z70.13 (~R); also elsewhere on the board
/Cassette Interface/MODESEL: Z43.1 (S); also elsewhere on the board
/Video/Video Access Multiplexer/C0: Z43.7 (Zb); also elsewhere on the board
/Video/Video Access Multiplexer/C1: Z65.9 (Q1); also elsewhere on the board
/Video/Video Access Multiplexer/C2: Z50.14 (CP0), Z65.8 (Q2); also elsewhere on the board
/Video/Video Access Multiplexer/C3: Z50.1 (CP1..3), Z50.12 (Q0); also elsewhere on the board
/Video/Video Access Multiplexer/C4: Z50.9 (Q1), Z66.3; also elsewhere on the board
/Video/Video Access Multiplexer/C5: Z50.8 (Q2), Z66.5; also elsewhere on the board
/Video/Video Access Multiplexer/R0: Z32.14 (CP0), Z65.12 (Q0); also elsewhere on the board
/Video/Video Access Multiplexer/R1: Z32.1 (CP1..3), Z32.12 (Q0), Z66.13; also elsewhere on the board
/Video/Video Access Multiplexer/R2: Z32.9 (Q1), Z66.2; also elsewhere on the board
/Video/Video Access Multiplexer/R3: Z32.8 (Q2); also elsewhere on the board
/Video/Video Counter/HDRV: Z12.14 (CP0), Z50.11 (Q3), Z66.4; also elsewhere on the board
/Video/Video Counter/L0: Z12.1 (CP1..3), Z12.12 (Q0); also elsewhere on the board
/Video/Video Counter/L1: Z12.9 (Q1); also elsewhere on the board
/Video/Video Counter/L2: Z12.8 (Q2), Z66.9, Z66.10; also elsewhere on the board
/Video/Video Counter/L3: Z12.11 (Q3), Z65.14 (CP0), Z66.11; also elsewhere on the board
/Video/Video Counter/SHIFT: Z43.4 (Za), Z58.14 (CP0); also elsewhere on the board
/Video/Video Counter/VDRV: Z32.11 (Q3), Z66.1; also elsewhere on the board
/Video/Video Counter/~LATCH: Z24.3; also elsewhere on the board
GND: Z12.10 (GND), Z32.10 (GND), Z43.5 (I0b), Z43.8 (GND), Z43.15 (E), Z50.10 (GND), Z58.6 (R0(1)), Z58.7 (R0(2)), Z58.10 (GND), Z65.2 (R0(1)), Z65.3 (R0(2)), Z65.10 (GND), Z66.7 (GND); also elsewhere on the board
unnamed: Z12.2 (R0(1)), Z12.3 (R0(2)), Z66.8
unnamed: Z32.2 (R0(1)), Z32.3 (R0(2)), Z66.12
unnamed: Z43.2 (I0a), Z70.9 (Q)
unnamed: Z24.2, Z43.11 (I0c), Z58.9 (Q2)
unnamed: Z43.6 (I1b), Z43.10 (I1c), Z58.8 (Q3)
unnamed: Z43.9 (Zc), Z65.1 (CP1..3)
unnamed: Z50.2 (R0(1)), Z50.3 (R0(2)), Z66.6
unnamed: Z24.1, Z58.1 (CP1..3), Z58.12 (Q0)
unnamed: Z70.8 (~Q), Z70.12 (D)

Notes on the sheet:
BIT 1
7.92 kHz
CLK/2
660 Hz
CP0/2
1.98 kHz
60 Hz
887.042 kHz
1.32 kHz
Character line counter
82.5 Hz
27.72 kHz
Mode Selector
CP0/11
3.96 kHz
110.88 kHz
CP1/4
221.76 kHz
55.44 kHz
15.84 kHz
CP0/6
CP0/12
BIT 3
330 Hz
Column counter
Row counter
10.6445 MHz
5.322 MHz
443.52 kHz
CP0/14
165 Hz
Every 6th count

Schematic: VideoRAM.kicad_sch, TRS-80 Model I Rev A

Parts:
Z30: 74LS02; TRS80_Model_I_DIP14
Z44, Z60: 74LS367; TRS80_Model_I_DIP16
Z45, Z46, Z47, Z48, Z61, Z62, Z63: 2102; TRS80_Model_I_DIP16

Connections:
+5V: Z45.10 (VCC), Z46.10 (VCC), Z47.10 (VCC), Z48.10 (VCC), Z60.16 (VCC), Z61.10 (VCC), Z62.10 (VCC), Z63.10 (VCC); also elsewhere on the board
/D0: Z44.7, Z48.11 (IN); also elsewhere on the board
/D1: Z44.5, Z47.11 (IN); also elsewhere on the board
/D2: Z44.3, Z46.11 (IN); also elsewhere on the board
/D3: Z44.9, Z45.11 (IN); also elsewhere on the board
/D4: Z60.9, Z61.11 (IN); also elsewhere on the board
/D5: Z60.7, Z62.11 (IN); also elsewhere on the board
/D6: Z60.5; also elsewhere on the board
/D7: Z60.3, Z63.11 (IN); also elsewhere on the board
/Video/Video Access Multiplexer/VA0: Z45.8 (A0), Z46.8 (A0), Z47.8 (A0), Z48.8 (A0), Z61.8 (A0), Z62.8 (A0), Z63.8 (A0); also elsewhere on the board
/Video/Video Access Multiplexer/VA1: Z45.4 (A1), Z46.4 (A1), Z47.4 (A1), Z48.4 (A1), Z61.4 (A1), Z62.4 (A1), Z63.4 (A1); also elsewhere on the board
/Video/Video Access Multiplexer/VA2: Z45.5 (A2), Z46.5 (A2), Z47.5 (A2), Z48.5 (A2), Z61.5 (A2), Z62.5 (A2), Z63.5 (A2); also elsewhere on the board
/Video/Video Access Multiplexer/VA3: Z45.6 (A3), Z46.6 (A3), Z47.6 (A3), Z48.6 (A3), Z61.6 (A3), Z62.6 (A3), Z63.6 (A3); also elsewhere on the board
/Video/Video Access Multiplexer/VA4: Z45.7 (A4), Z46.7 (A4), Z47.7 (A4), Z48.7 (A4), Z61.7 (A4), Z62.7 (A4), Z63.7 (A4); also elsewhere on the board
/Video/Video Access Multiplexer/VA5: Z45.2 (A5), Z46.2 (A5), Z47.2 (A5), Z48.2 (A5), Z61.2 (A5), Z62.2 (A5), Z63.2 (A5); also elsewhere on the board
/Video/Video Access Multiplexer/VA6: Z45.1 (A6), Z46.1 (A6), Z47.1 (A6), Z48.1 (A6), Z61.1 (A6), Z62.1 (A6), Z63.1 (A6); also elsewhere on the board
/Video/Video Access Multiplexer/VA7: Z45.16 (A7), Z46.16 (A7), Z47.16 (A7), Z48.16 (A7), Z61.16 (A7), Z62.16 (A7), Z63.16 (A7); also elsewhere on the board
/Video/Video Access Multiplexer/VA8: Z45.15 (A8), Z46.15 (A8), Z47.15 (A8), Z48.15 (A8), Z61.15 (A8), Z62.15 (A8), Z63.15 (A8); also elsewhere on the board
/Video/Video Access Multiplexer/VA9: Z45.14 (A9), Z46.14 (A9), Z47.14 (A9), Z48.14 (A9), Z61.14 (A9), Z62.14 (A9), Z63.14 (A9); also elsewhere on the board
/Video/Video Access Multiplexer/~VRD: Z44.1, Z60.1; also elsewhere on the board
/Video/Video Access Multiplexer/~VWR: Z45.3 (R/~W), Z46.3 (R/~W), Z47.3 (R/~W), Z48.3 (R/~W), Z61.3 (R/~W), Z62.3 (R/~W), Z63.3 (R/~W); also elsewhere on the board
/Video/Video Latch/VD0: Z44.6, Z48.12 (OUT); also elsewhere on the board
/Video/Video Latch/VD1: Z44.4, Z47.12 (OUT); also elsewhere on the board
/Video/Video Latch/VD2: Z44.2, Z46.12 (OUT); also elsewhere on the board
/Video/Video Latch/VD3: Z44.10, Z45.12 (OUT); also elsewhere on the board
/Video/Video Latch/VD4: Z60.10, Z61.12 (OUT); also elsewhere on the board
/Video/Video Latch/VD5: Z30.12, Z60.6, Z62.12 (OUT); also elsewhere on the board
/Video/Video Latch/VD6: Z30.13, Z60.4; also elsewhere on the board
/Video/Video Latch/VD7: Z30.11, Z60.2, Z63.12 (OUT); also elsewhere on the board
GND: Z45.9 (GND), Z45.13 (~CE), Z46.9 (GND), Z46.13 (~CE), Z47.9 (GND), Z47.13 (~CE), Z48.9 (GND), Z48.13 (~CE), Z60.8 (GND), Z60.12, Z60.14, Z60.15, Z61.9 (GND), Z61.13 (~CE), Z62.9 (GND), Z62.13 (~CE), Z63.9 (GND), Z63.13 (~CE); also elsewhere on the board

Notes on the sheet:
Derived BIT 6
BIT 5
BIT 7

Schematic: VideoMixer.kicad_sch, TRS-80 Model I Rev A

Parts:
C2: 10uF 16V; TRS80_Model_I_C_Pol_Radial_5D_2.5P
C7: 0.01uF 24V; TRS80_Model_I_C_Disc_9.5L_4W_6P_Small
J2: Front View; TRS80_Model_I_DIN5
Q1: 2N3904; TRS80_Model_I_Q_Circle_EBC
Q2: 2N3906; TRS80_Model_I_Q_Circle_EBC
R22: 75; TRS80_Model_I_R_0.25W
R23: 120; TRS80_Model_I_R_0.25W
R27: 330; TRS80_Model_I_R_0.25W
R28: 270; TRS80_Model_I_R_0.25W
R29: 1.8k; TRS80_Model_I_R_0.25W
R30: 47; TRS80_Model_I_R_0.25W
Z41: 75452; TRS80_Model_I_DIP8

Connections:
+5V: J2.1, Q2.1 (E), R30.1; also elsewhere on the board
/Video/Video Generator/PIXEL: Z41.6 (2A), Z41.7 (2B); also elsewhere on the board
/Video/Video Mixer/SYNC: R29.1; also elsewhere on the board
GND: C2.2, C7.2, J2.5, R22.2, R27.2; also elsewhere on the board
unnamed: Q1.2 (B), R23.1, R27.1, R28.2
unnamed: C2.1, C7.1, Q1.3 (C), R30.2
unnamed: J2.4, Q1.1 (E), R22.1
unnamed: Q2.2 (B), R29.2
unnamed: Q2.3 (C), R28.1
unnamed: R23.2, Z41.5 (2Y)

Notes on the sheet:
Q2 open, Z41 any => 0V (sync level) Q2 closed, Z41 closed => 1.23V (black level) - R28 with series resistors R23 & R27 Q2 closed, Z41 open => 2.75V (white level) - Only R27 & R28

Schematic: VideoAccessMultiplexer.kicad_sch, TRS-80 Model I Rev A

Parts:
R49: 4.7k; TRS80_Model_I_R_0.25W
Z31, Z49, Z64: 74LS157; TRS80_Model_I_DIP16

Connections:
+5V: R49.1, Z31.16 (VCC), Z49.16 (VCC), Z64.16 (VCC); also elsewhere on the board
/A0: Z64.11 (I0c); also elsewhere on the board
/A1: Z64.2 (I0a); also elsewhere on the board
/A2: Z64.14 (I0d); also elsewhere on the board
/A3: Z64.5 (I0b); also elsewhere on the board
/A4: Z49.11 (I0c); also elsewhere on the board
/A5: Z49.2 (I0a); also elsewhere on the board
/A6: Z31.11 (I0c); also elsewhere on the board
/A7: Z31.14 (I0d); also elsewhere on the board
/A8: Z31.2 (I0a); also elsewhere on the board
/A9: Z31.5 (I0b); also elsewhere on the board
/Address Decoder/~RD: Z49.5 (I0b); also elsewhere on the board
/Address Decoder/~VID: Z31.1 (S), Z49.1 (S), Z64.1 (S); also elsewhere on the board
/CPU Gating/~WR: Z49.14 (I0d); also elsewhere on the board
/Video/Video Access Multiplexer/C0: Z64.10 (I1c); also elsewhere on the board
/Video/Video Access Multiplexer/C1: Z64.3 (I1a); also elsewhere on the board
/Video/Video Access Multiplexer/C2: Z64.13 (I1d); also elsewhere on the board
/Video/Video Access Multiplexer/C3: Z64.6 (I1b); also elsewhere on the board
/Video/Video Access Multiplexer/C4: Z49.10 (I1c); also elsewhere on the board
/Video/Video Access Multiplexer/C5: Z49.3 (I1a); also elsewhere on the board
/Video/Video Access Multiplexer/R0: Z31.10 (I1c); also elsewhere on the board
/Video/Video Access Multiplexer/R1: Z31.13 (I1d); also elsewhere on the board
/Video/Video Access Multiplexer/R2: Z31.3 (I1a); also elsewhere on the board
/Video/Video Access Multiplexer/R3: Z31.6 (I1b); also elsewhere on the board
/Video/Video Access Multiplexer/VA0: Z64.9 (Zc); also elsewhere on the board
/Video/Video Access Multiplexer/VA1: Z64.4 (Za); also elsewhere on the board
/Video/Video Access Multiplexer/VA2: Z64.12 (Zd); also elsewhere on the board
/Video/Video Access Multiplexer/VA3: Z64.7 (Zb); also elsewhere on the board
/Video/Video Access Multiplexer/VA4: Z49.9 (Zc); also elsewhere on the board
/Video/Video Access Multiplexer/VA5: Z49.4 (Za); also elsewhere on the board
/Video/Video Access Multiplexer/VA6: Z31.9 (Zc); also elsewhere on the board
/Video/Video Access Multiplexer/VA7: Z31.12 (Zd); also elsewhere on the board
/Video/Video Access Multiplexer/VA8: Z31.4 (Za); also elsewhere on the board
/Video/Video Access Multiplexer/VA9: Z31.7 (Zb); also elsewhere on the board
/Video/Video Access Multiplexer/~VRD: Z49.7 (Zb); also elsewhere on the board
/Video/Video Access Multiplexer/~VWR: Z49.12 (Zd); also elsewhere on the board
GND: Z31.8 (GND), Z31.15 (E), Z49.8 (GND), Z49.15 (E), Z64.8 (GND), Z64.15 (E); also elsewhere on the board
unnamed: R49.2, Z49.6 (I1b), Z49.13 (I1d)

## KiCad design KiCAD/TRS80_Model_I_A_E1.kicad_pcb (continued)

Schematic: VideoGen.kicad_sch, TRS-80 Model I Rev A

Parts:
R40: 4.7k; TRS80_Model_I_R_0.25W
Z8: 74LS153; TRS80_Model_I_DIP16
Z9: 74LS04; TRS80_Model_I_DIP14
Z10, Z11: 74LS166; TRS80_Model_I_DIP16
Z26: 74LS20; TRS80_Model_I_DIP14
Z29: MCM6670; TRS80_Model_I_DIP18
Z30: 74LS02; TRS80_Model_I_DIP14

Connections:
+5V: R40.2, Z8.16 (VCC), Z9.14 (VCC), Z10.16 (VCC), Z11.16 (VCC), Z26.14 (VCC), Z29.18 (VCC); also elsewhere on the board
/Video/Video Counter/L0: Z29.11 (R0); also elsewhere on the board
/Video/Video Counter/L1: Z29.10 (R1); also elsewhere on the board
/Video/Video Counter/L2: Z8.14 (S0), Z29.8 (R2); also elsewhere on the board
/Video/Video Counter/L3: Z8.2 (S1); also elsewhere on the board
/Video/Video Counter/SHIFT: Z9.9; also elsewhere on the board
/Video/Video Counter/~LATCH: Z9.3; also elsewhere on the board
/Video/Video Generator/GRAPHICS: Z26.4; also elsewhere on the board
/Video/Video Generator/LB0: Z8.6 (I0a), Z29.7 (A0); also elsewhere on the board
/Video/Video Generator/LB1: Z8.10 (I0b), Z29.6 (A1); also elsewhere on the board
/Video/Video Generator/LB2: Z8.5 (I1a), Z29.5 (A2); also elsewhere on the board
/Video/Video Generator/LB3: Z8.11 (I1b), Z29.4 (A3); also elsewhere on the board
/Video/Video Generator/LB4: Z8.4 (I2a), Z29.3 (A4); also elsewhere on the board
/Video/Video Generator/LB5: Z8.12 (I2b), Z29.2 (A5); also elsewhere on the board
/Video/Video Generator/LB6: Z29.1 (A6); also elsewhere on the board
/Video/Video Generator/PIXEL: Z30.1; also elsewhere on the board
/Video/Video Generator/~BLANK: Z26.1, Z26.2, Z26.9; also elsewhere on the board
/Video/Video Generator/~CHARGAP: Z26.12; also elsewhere on the board
/Video/Video Generator/~GRAPHICS: Z26.10; also elsewhere on the board
GND: Z8.1 (Ea), Z8.8 (GND), Z8.15 (Eb), Z9.1, Z9.5, Z9.7 (GND), Z9.11, Z9.13, Z10.1 (Ds), Z10.2 (A), Z10.3 (B), Z10.6 (CE), Z10.8 (GND), Z10.14 (H), Z11.1 (Ds), Z11.2 (A), Z11.3 (B), Z11.6 (CE), Z11.8 (GND), Z26.7 (GND), Z29.9 (GND), Z29.17 (~CS); also elsewhere on the board
unnamed: Z10.4 (C), Z29.12 (D0)
unnamed: Z9.8, Z10.7 (Clk), Z11.7 (Clk)
unnamed: R40.1, Z10.9 (Clr), Z11.9 (Clr)
unnamed: Z10.5 (D), Z29.13 (D1)
unnamed: Z10.10 (E), Z29.14 (D2)
unnamed: Z10.11 (F), Z29.15 (D3)
unnamed: Z10.12 (G), Z29.16 (D4)
unnamed: Z10.15 (PE), Z26.8
unnamed: Z10.13 (Qh), Z30.3
unnamed: Z8.9 (Zb), Z11.4 (C), Z11.5 (D), Z11.10 (E)
unnamed: Z8.7 (Za), Z11.11 (F), Z11.12 (G), Z11.14 (H)
unnamed: Z11.15 (PE), Z26.6
unnamed: Z11.13 (Qh), Z30.2
unnamed: Z9.4, Z26.5, Z26.13

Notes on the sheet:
ASCII
SHIFT/~{LOAD}
LATCH
Right
GRAPHICS PIXEL
Left
Character Generator
GRAPHICS
~{SHIFT}
ASCII PIXEL
Inversed Clock (delays clock)

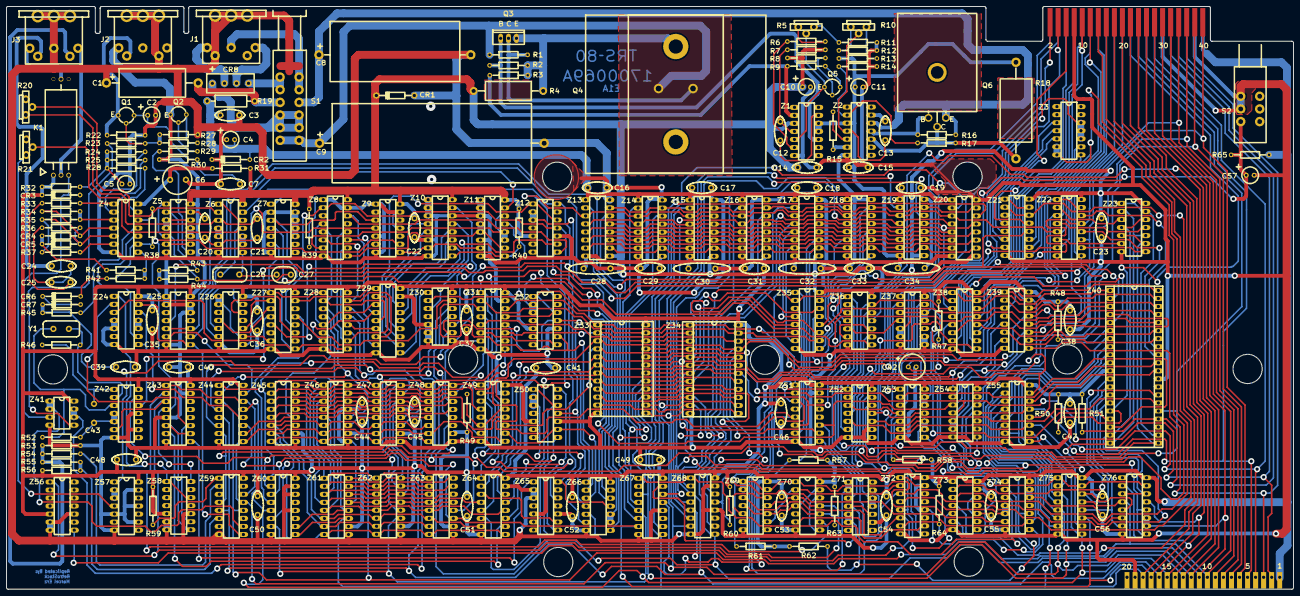
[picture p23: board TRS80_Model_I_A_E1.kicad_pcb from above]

Board: 2 copper layers, 406.8 x 184.2 mm, 221 parts (0 on the bottom side), 297 nets.
